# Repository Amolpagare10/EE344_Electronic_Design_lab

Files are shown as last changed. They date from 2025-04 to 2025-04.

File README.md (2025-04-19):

<!-- Modify from here -->
# Project Overview    

### Project Name: *EcoSync 8X* - A dsPIC33A microcontroller based ultrasonic guided wave structural health monitoring system
### Team Number: TUE-08

### Team Members:  
(in alphabetical order)
- **[Amol Pagare](https://github.com/Amolpagare10)**
- **[Angad Singh](https://github.com/lightning-starboy)**  
- **[Anuj Gautam](https://github.com/10Anuj)**  
- **[Anuj Yadav](https://github.com/anujyadav10457)**  
- **[Subhanshu Choudhary](https://github.com/Subhanshu-Leo)**

## Problem Statement and Solution

This project introduces an **embedded data acquisition system** using **ultrasonic guided wave–based structural inspection**. The system is built around an **8-channel transducer interface**, where each channel can be dynamically configured as either a **transmitter** or **receiver**, enabling flexible and reconfigurable testing setups—all controlled via a user-friendly **graphical user interface (GUI)**.This is the device [User Manual.](others/USER_MANUAL.pdf)

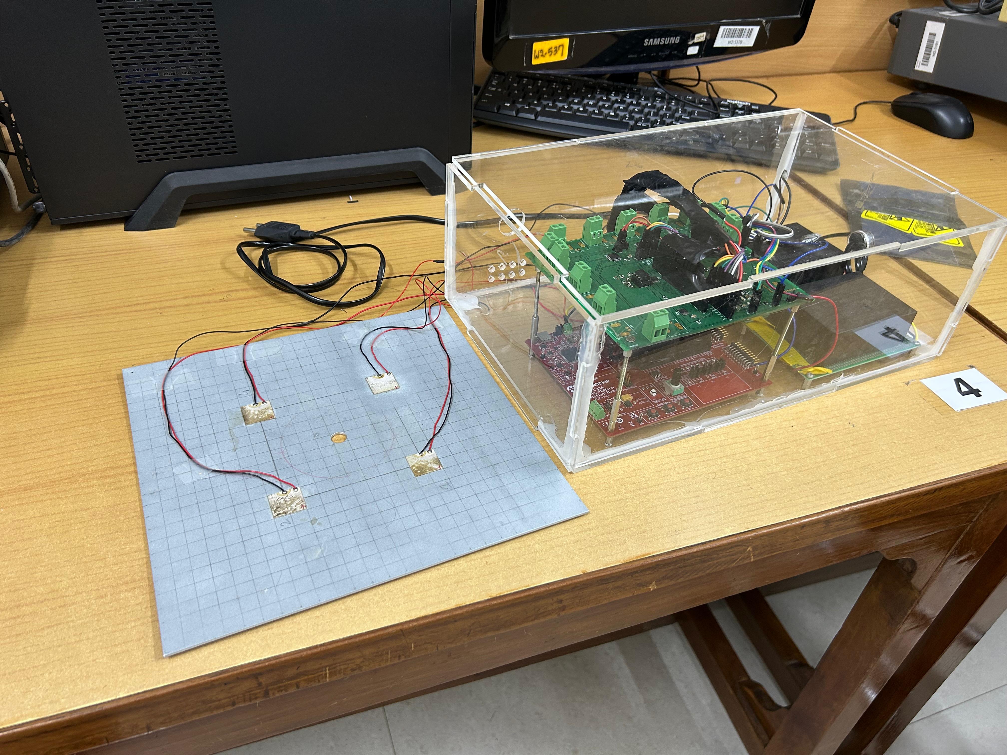
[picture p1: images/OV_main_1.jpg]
  

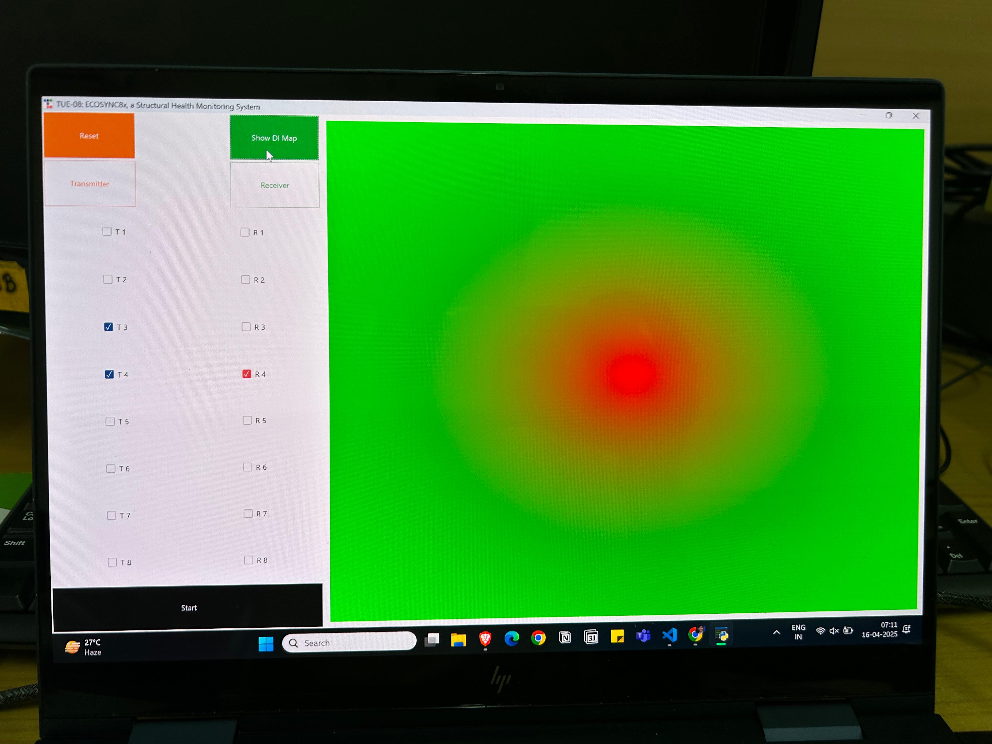
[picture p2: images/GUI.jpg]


---

### Key Features:

- **Signal Generation**: Produces a 100 kHz, 5-cycle Hanning-windowed pulse with a 10 V<sub>pp</sub> amplitude, which can be amplified up to 100 V<sub>pp</sub> using an external power amplifier.
- **Receiver Signal**: Includes high-fidelity signal acquisition with instrumentation amplifiers for accurate and noise-reduced signal capture.
- **Channel Multiplexing**: Supports 8-channel multiplexing for dynamic selection of transmitter and receiver transducers.
- **Wireless Communication**: Enables real-time data transmission to a host computer for visualization and offline analysis.
- **Structural Health Monitoring**: Ideal for applications in pipelines, metal and composite panels, and other critical infrastructure requiring long-term monitoring and inspection.
  <!-- <img src="images/" width="500"> -->

## 1. Source Code
### Project Directory Structure

```
/Project-Root
├── /src                      # Source code folder
│   ├── /dspic33ak128MC106      # Microcontroller 1
│   │   ├── integrated.c          # Handles DAC and ADC functionality
│   │   ├── command_protocol.c    # Implements the command protocol logic
│   │   ├── protocol_def.h        # Definitions for the command protocol
│   │
│   ├── /esp32                  # Microcontroller 2
│   │   ├── wifi_code.ino         # WiFi setup and communication code
```

### Programming the Microcontrollers

For programming the **dsPIC33AK128MC106** microcontroller, we used **MPLAB X IDE** in combination with the **XC-DSC compiler**.  
For the **ESP32** module, the programming was done using the **Arduino IDE**.  
In both cases, the code was written in the **C programming language**.

---

### How to Use the Code

### 1. Install Required Tools

- **MPLAB X IDE**: The official integrated development environment provided by Microchip for developing and debugging embedded applications.
- **XC-DSC Compiler**: A compiler specifically designed for 16-bit Digital Signal Controllers (DSCs) like the dsPIC33 series.

Both tools can be downloaded from the Microchip website:  
[https://www.microchip.com/en-us/tools-resources/develop/mplab-x-ide](https://www.microchip.com/en-us/tools-resources/develop/mplab-x-ide)

---

### 2. Creating a New Project in MPLAB X IDE

Once the tools are installed, follow these steps to create and configure a new project for the dsPIC33AK128MC106:

1. **Launch MPLAB X IDE**.
2. Go to the **File** menu and select **New Project**.
3. In the project wizard:
    - Select **Microchip Embedded** under **Categories**
    - Select **Application Projects** under **Projects**  
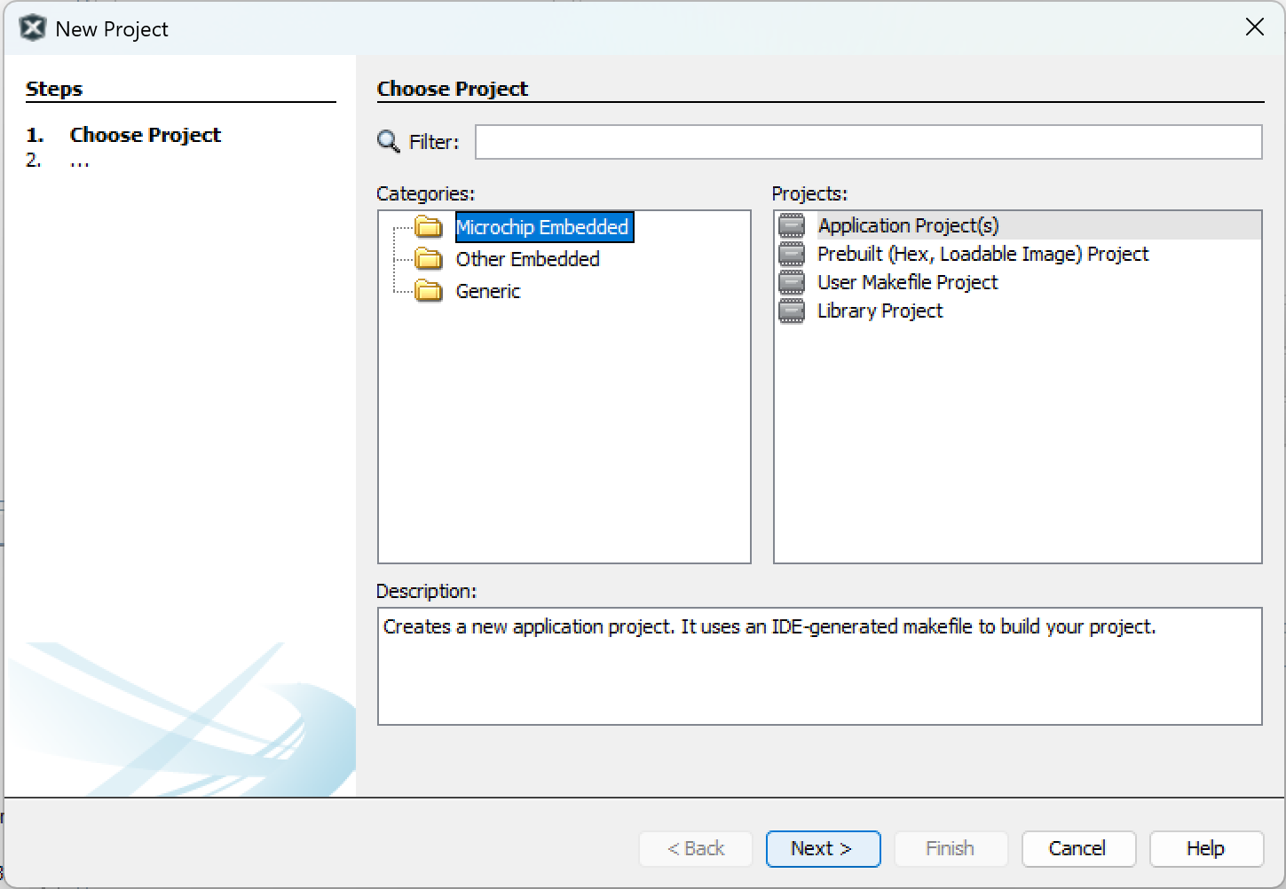
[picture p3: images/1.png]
      
4. Click **Next**, then:
    - Choose **16-bit DSCs (dsPIC33)** from the **Family** dropdown
    - Select **dsPIC33AK128MC106** from the list of devices  
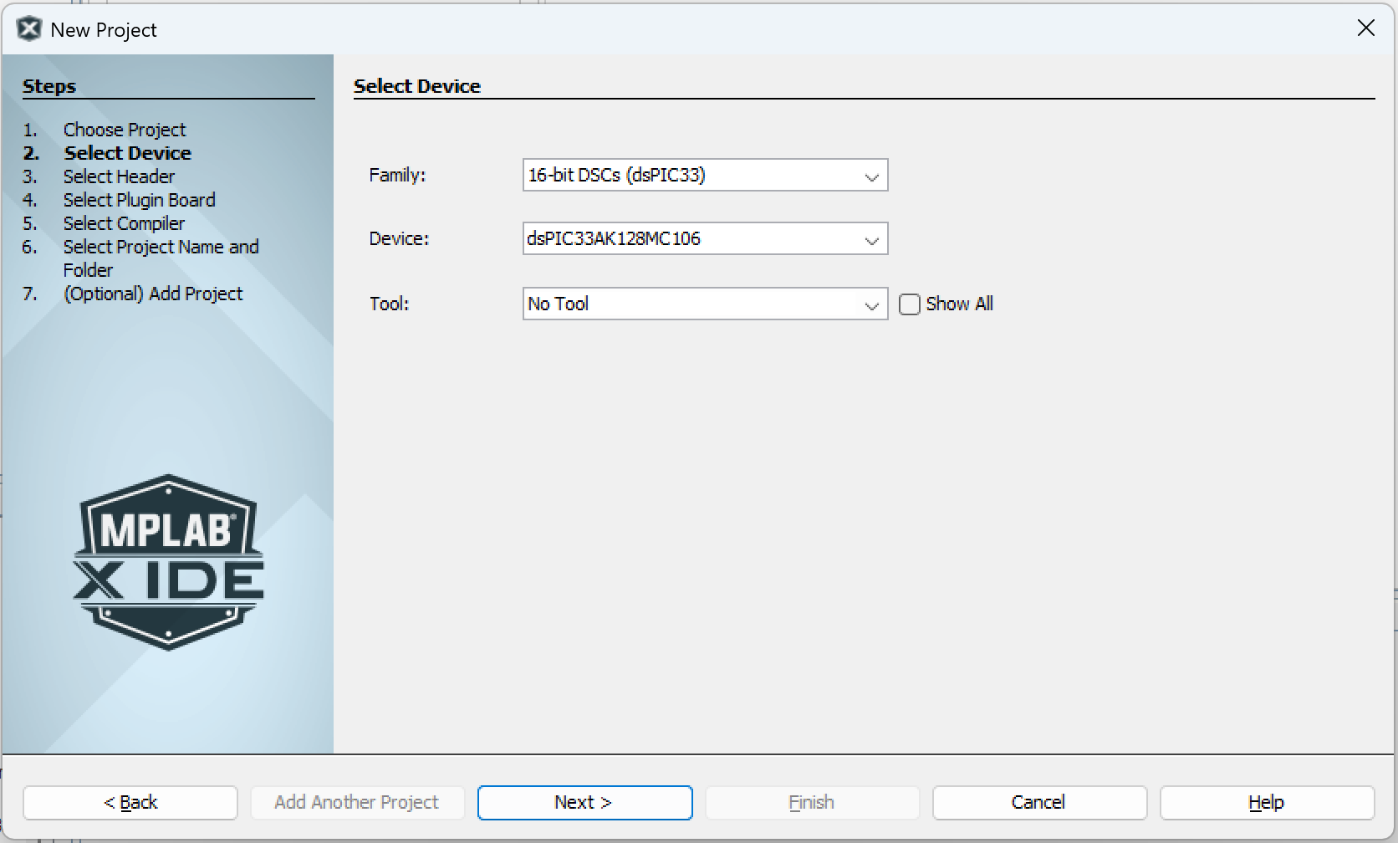
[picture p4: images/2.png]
      
5. Click **Next**, then choose the **XC-DSC** compiler from the list of available compilers  
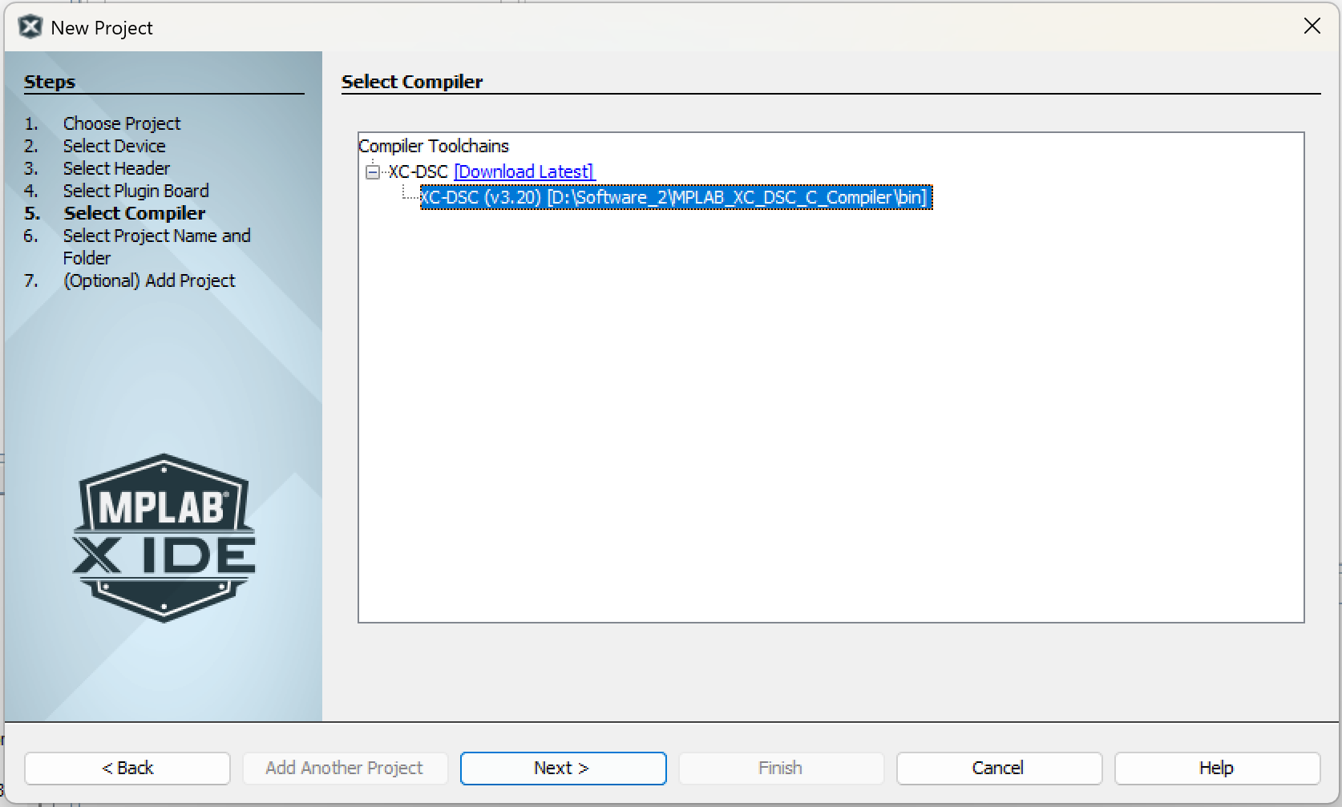
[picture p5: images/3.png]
   
6. Provide a name for your project and choose a directory where it will be saved  
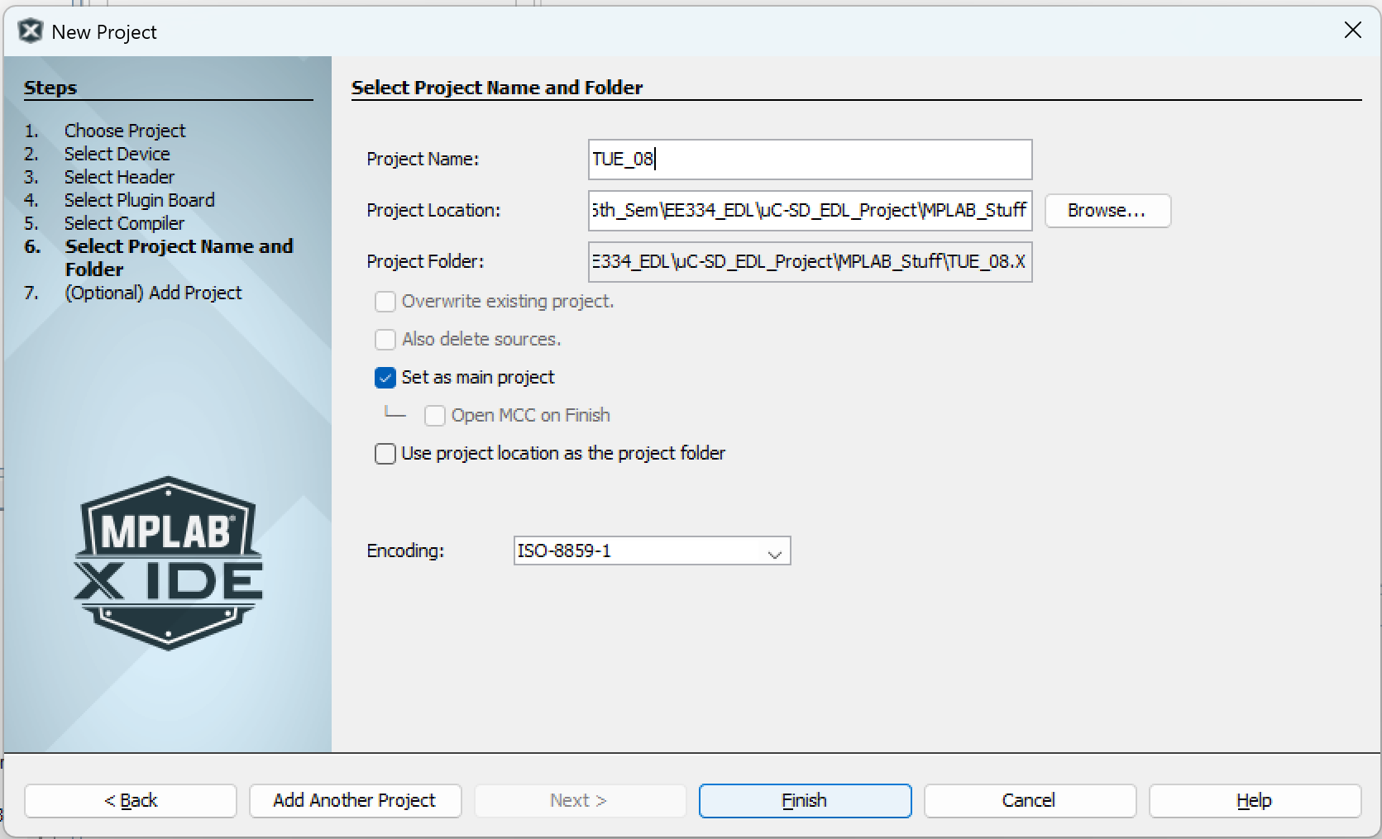
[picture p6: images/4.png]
   

---

### 3. Adding Source Code Files

Once your project is set up:

1. In the **Projects** tab within MPLAB X IDE, navigate to the `Source Files` folder.
2. Copy and paste the provided `.c` and `.h` files into the `Source Files` directory.  

---

### 4. Building and Programming the Device

To compile and upload your code:

1. Click on the **Build Project** button (hammer icon) in the toolbar to compile the code.  
   
2. After a successful build, click the **Make and Program Device** button (downward arrow icon) to upload the code to the microcontroller.  
   
3. Once the microcontroller is programmed successfully, the onboard **status LED** should start blinking, indicating that the code is running.

---

## 2. PCB Design
```
/Project-Root
├──pcb/
|  ├── pictures/                         # Existing folder
|  ├── 1N914.zip                         # Diode library
|  ├── LIB_23LCV04M-I_ST.zip            # Official library
|  ├── LIB_DAC7821IPWR.zip              # Official DAC library
|  ├── MAX1426EAI_.zip                  # ADC or other component library
|  ├── Readme.md                        # Main documentation or instructions
|  ├── design.kicad_pcb                 # KiCAD PCB layout
|  ├── design.kicad_pro                 # KiCAD project file
|  ├── design.kicad_sch                 # KiCAD schematic file
|  ├── ul_DAC7821IPW.zip                # User-provided DAC library
|  ├── ul_INA128U.zip                   # User-provided instrumentation amp
|  ├── ul_TL072CP.zip                   # User-provided op-amp library
```
We've made our PCB using KiCAD software and these are the footprints used in the PCB design.

## 3. Laser Cut Panels
### Enclosure Design and Fabrication

The enclosure for our project was custom-designed and fabricated using **laser cutting**. All design files are located in the `/3d_models` directory. The box design was created using **Autodesk Fusion 360** and exported as a **DXF file** suitable for laser cutting.
```
/Project-Root
├── /3d_models              # 3D models and laser cut files
│   ├── box_model.dxf         # DXF file with all 6 faces for laser cutting
│   ├── Box_CAD_Sketch.png    # Sketch preview of the box design
```

### Box Details

- The enclosure consists of **six interlocking acrylic panels**, each precisely designed with **notches** that fit into complementary notches on adjacent panels for seamless assembly.
- Panels are cut from **5 mm thick acrylic sheets**.
- The box is assembled using **hot glue**, which securely holds the panels together.

---

### Custom Cutouts

- **Back Panel**:
  - Includes a cutout for the **power supply**.
- **Side Panel**:
  - It has a cutout specifically for the **dsPIC33AK128MC106 microcontroller board**.
  - Below the microcontroller cutout, there are **eight holes** for the **transducer connectors**, allowing easy interfacing with the external sensors.

## 4. Bill Of Materials  
This project involves various electronic components including microcontrollers, converters, sensors, and support modules, sourced from vendors like DigiKey, Robu, Mouser, and Microchip.

### Component Overview

| **Category** | **Component** | **Quantity** | **Vendor** | **Cost (INR)** |
|---|---|---|---|---|
| **Microcontrollers & Dev Boards** | ESP32 WiFi Module, DIM Module, Development Board | 3 | DigiKey, Microchip | ₹9,457.00 |
| **Signal Conversion** | DAC, ADC, INA128 | 3 | Mouser, DigiKey, Robu | ₹1,910.00 |
| **Power Modules** | SMPS (x2), Buck & Boost Converters | 5 | DigiKey, Robu | ₹4,420.00 |
| **Sensors** | PZT Sensor (SP-5H) | 8 | CPS Lab | ₹40,000.00 |
| **Misc ICs** | MUX, Electronic Switch, Opamp | 3 | Mouser, DigiKey, Robu | ₹2,675.00 |
| **Mechanical** | Acrylic Sheet Panels (Laser Cut) | 6 | WEL | NA |

---

### **Total Cost**: ₹58,462.00

> Note: Cost for acrylic sheets not included.

## **Learning, Experiences, Hardships, and Difficulties Encountered**

<!-- This course has been a valuable learning experience for us. It taught us how to transform an idea into a tangible product, which was both challenging and exciting. Throughout the project, we experienced highs when things were progressing smoothly, when our DAC wasn't giveing the correct waveform, as well as lows when nothing seemed to work despite our efforts, when our ADC couldnt't work reliably. There were moments of frustration, especially when technical setbacks slowed us down or when not all team members could contribute equally due to other academic commitments, even when we had quizes and exam, we tried to invest some time according to our free timings. In hindsight, we believe a more effective distribution of tasks could have helped us manage these challenges better. Nonetheless, the journey was immensely enriching, and we’re grateful for the opportunity to learn and grow through this experience. -->

This course has been a valuable learning experience for us. It taught us how to transform an idea into a tangible product, which was both challenging and exciting. 

Throughout the project, we experienced several highs—such as when things were progressing smoothly—and lows, like when our DAC wasn't giving the correct waveform or when our ADC couldn’t work reliably. 

There were moments of frustration, especially when technical setbacks slowed us down or when not all team members could contribute equally due to other academic commitments. Even during quizzes and exams, we tried to invest time according to our free schedules.

In hindsight, we believe a more effective distribution of tasks could have helped us manage these challenges better. Nonetheless, the journey was immensely enriching, and we’re grateful for the opportunity to learn and grow through this experience.

## Current status and Future Prospects for our Project

---

### 1. Partially Incomplete ADC

#### What Was Done:
- Tested the ADC on the PCB using waveform inputs from the INA.
- Output signal remained constant across tests.
- Tried using an earlier-working ADC on a breadboard—still observed a constant output.

#### Unresolved Issues:
The root cause remains unidentified. Potential issues could include:
- Incorrect voltage reference.
- INA output entering saturation.
- Firmware misconfiguration.
- Inaccurate or missing clock signals.

#### Parts Not Completed:
- Full integration of the ADC into the signal chain.
- Validation using real digitized sensor data.
- Establishing a complete end-to-end data acquisition pipeline for signal processing.

---

### 2. Partially Incomplete Wi-Fi Module Interface

#### What Was Done:
- Attempted UART-based interfacing of the Wi-Fi module with the Curiosity board.
- Identified that the UART pins on the board were non-functional.

#### Progress Made:
- Successfully interfaced the Wi-Fi module with a GUI.
- Enabled both data transmission and reception.
- Initially received garbage data when connected to a laptop, resolved by:
  - Splitting the code into two modules:
    - One for the Wi-Fi module at **115200 baud rate**.
    - One for laptop communication at **9600 baud rate**.

#### Parts Not Completed:
- Wi-Fi integration with the Curiosity board.
- Wireless transmission of sensor data from the MCU.
- Real-time wireless data logging and remote visualization.

---

## Future Prospects

### 1. Enhanced GUI Interface
- Develop a more intuitive and interactive GUI.
- Key features to include:
  - Real-time waveform plotting.
  - Diagnostic alerts for system anomalies.
  - Interactive signal control and parameter tuning.

### 2. DI Map Algorithm Improvements
- Optimize the **Damage Index (DI)** mapping algorithm for better defect localization and embedded performance.
- Add a validation metric to evaluate and improve accuracy.
- Enable dynamic updates on the GUI for visual feedback.

### 3. Complete Wi-Fi Module Integration
- Finalize integration of the Wi-Fi module with the Curiosity board.
- Support seamless, real-time wireless data transmission.
- Enable remote monitoring through a web interface or mobile application.

### 4. SRAM-Based Memory Expansion
- Integrate external **SRAM** to overcome microcontroller memory limitations.
- Support:
  - High-resolution signal logging.
  - Buffered data acquisition.
  - Advanced signal processing tasks on-device.

---

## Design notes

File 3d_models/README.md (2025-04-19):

# Enclosure Design and Construction
We had a simple enclosure design for our project, which was primarily focused on housing the electronics and providing access to the necessary ports. 

## Design Software
- The enclosure was designed using **Autodesk Fusion 360**, which provided a 3D parametric design environment.
- The final laser-cut layout was exported as a **DXF (Drawing Exchange Format)** file, the industry-standard format for 2D cutting paths.

---

## Box Construction Details

- **Material**: The panels were cut from **5 mm thick clear acrylic sheets**, offering a good balance between strength and aesthetics.
- **Structure**: The enclosure consists of **six interlocking panels** — top, bottom, front, back, and two sides.
- **Joinery**:
  - Each panel has precisely aligned **notches and tabs**, allowing them to fit together like puzzle pieces without additional fixtures.
  - These interlocks reduce the need for mechanical fasteners and improve ease of assembly.
- **Assembly**:
  - The panels are joined using **hot glue**, which offers strong adhesion while being easy to apply.
  - The enclosure is lightweight, transparent for visual inspection, and sturdy enough to house electronics safely.

---

## Custom Cutouts and Access Ports

Each panel was carefully designed with cutouts for interfacing components and ease of access:

- **Back Panel**:
  - Includes a circular slot for the **power supply input**.
  - Ensures that the AC-DC SMPS module or USB-powered units can be neatly connected without internal clutter.

- **Side Panel (Control Interface Panel)**:
  - Features a precise cutout for the **dsPIC33AK128MC106 microcontroller board** so that its USB/debug port remain externally accessible.
  - **Below the microcontroller**, there are **eight circular holes** which allow the connections to the **transducer connectors**.
    - These connectors interface with external **piezoelectric sensors**, and the holes ensure that cables can be plugged in directly without disassembling the box.

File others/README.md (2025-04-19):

# Graphical User Interface (GUI) Overview

Our GUI allows users to configure the **transmitter** and **receiver** setup of the transducers.

- Once the desired configuration is selected, users can **start transmission and reception** of ultrasonic signals.
- The results are then visualized on the GUI using a **HeatMap**.
- Currently, the **HeatMap is based on a pipe algorithm**, as the **Damage Index algorithm for plates** is still under study.
- For demonstration purposes, the pipe-based visualization will be used.

---

# User Manual – Key Instructions

## 1. Sensor Placement
- Mount piezoelectric sensors firmly on the plate following a planned layout.
- Maintain consistent spacing and ensure solid mechanical coupling.
- Clearly label each sensor for easy identification when assigning Tx/Rx roles.

## 2. Power Connection
- Plug the system into a **220V, 15A grounded socket**.
- Avoid using damaged plugs or loose/multi-plug extensions.
- This power connection supports the signal generation and data acquisition modules.

## 3. Wi-Fi Connection
- Connect your computer to the **Wi-Fi network** broadcast by the control box.
- No internet is needed — this is a local wireless connection.
- Ensure that firewall or antivirus settings do not block the communication port.

## 4. Sensor Configuration in Application
- Launch the **SHM (Structural Health Monitoring)** software.
- Assign transducers as **Transmitters (Tx)** and **Receivers (Rx)** via the interface.
- Choose sensor pairs that offer optimal coverage for the structure being analyzed.

## 5. Data Reception & DI Map Generation
- After configuration, signal data will be transmitted and collected.
- Once data is received, click the **orange button** in the GUI to generate the **Damage Index (DI) Map**.
- The DI Map highlights potential damage zones based on signal response characteristics.

---

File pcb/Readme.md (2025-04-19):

# PCB Design Issues:

- Our SMD INA on the PCB was not working. We replaced it with another SMD INA, but it still didn't work. Since we didn’t have any more SMD INAs, we used a DIP INA on a breadboard and connected it to the PCB — and it started working.

- In the ADC, we grounded the CMLP pin (pin 11), as the datasheet mentioned that for DC coupling, it should be grounded. However, during breadboard testing, we found that it worked when connected to 5V instead.

- Even after all this, the ADC on the PCB is still not working. We tried to figure out the issue by checking if the clock is working, if we are receiving data at the ADC, and if the power supply to the ADC is correct. We found that everything appears to be in order, yet we are still not receiving any data from the ADC.

# Purpose of the PCB:

- In our project, almost everything relied on the PCB. We had to use components like the DAC, TL072, power amplifier, electronic switch, multiplexer, INA, and ADC — all of which required reliable and organized connections. Using a PCB was the best choice to ensure clean and consistent wiring.

- Moreover, we found that small mistakes on the breadboard made debugging very cumbersome. In contrast, the PCB allowed us to make all the connections properly and verify them once. After the PCB arrived and we tested it, we could trust the setup and focus on the actual performance of the circuit.

# Explanation of PCB connections 

- Our microcontroller was connected to the DAC to convert digital data into analog signals. The signal was then passed through a TL072 and a power amplifier to amplify it. Next, an electronic switch was used to select which transducer would transmit the signal.

- After transmission, a multiplexer (MUX) was used to select the transducer that would receive the signal. The received signal was then passed through an INA and a clipper — the INA amplified the signal, while the clipper limited high voltages to protect the circuit.

- Finally, the processed analog signal was fed into an ADC to convert it back into digital form, which was then sent to the PC for post-processing.

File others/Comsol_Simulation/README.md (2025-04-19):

# Piezoelectric Sensor Excitation Simulations (COMSOL)

This repository contains simulation results from **COMSOL Multiphysics** illustrating various excitation scenarios of piezoelectric sensors embedded on a solid structure. The aim of these simulations is to study wave propagation and stress distribution in the material in response to controlled excitations.

---

## Overview

Piezoelectric sensors are commonly used in **Structural Health Monitoring (SHM)** systems to detect and localize defects through guided wave techniques. This project investigates how different excitation methods and sensor placements affect wave propagation and energy concentration in a simulated environment.

---

## Simulation 1

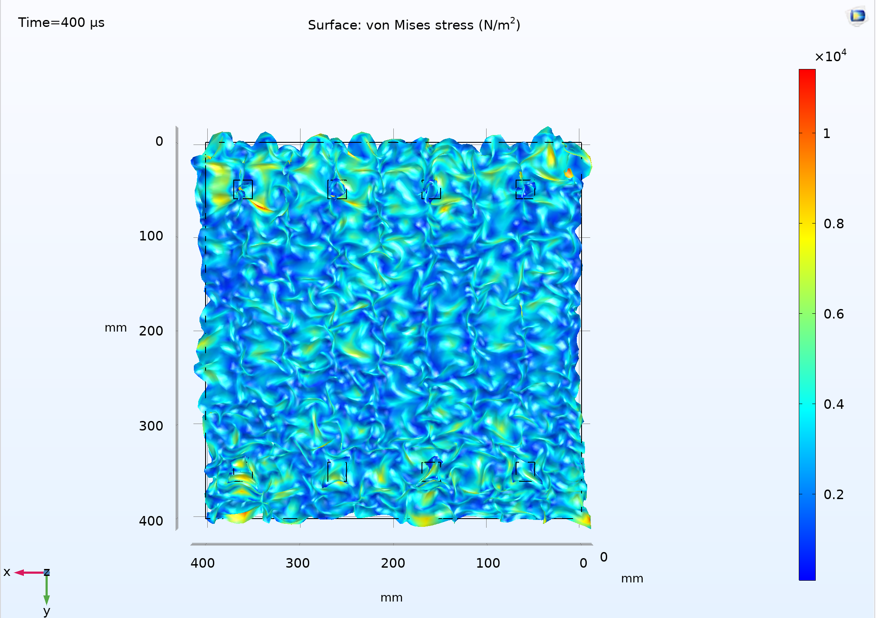
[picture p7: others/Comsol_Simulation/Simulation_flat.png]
Flat Plate view at 400µs


**Description:**  
This image shows wave propagation across the plate after excitation via PZT sensors, observed when the plate is placed flat.

---

## Simulation 2

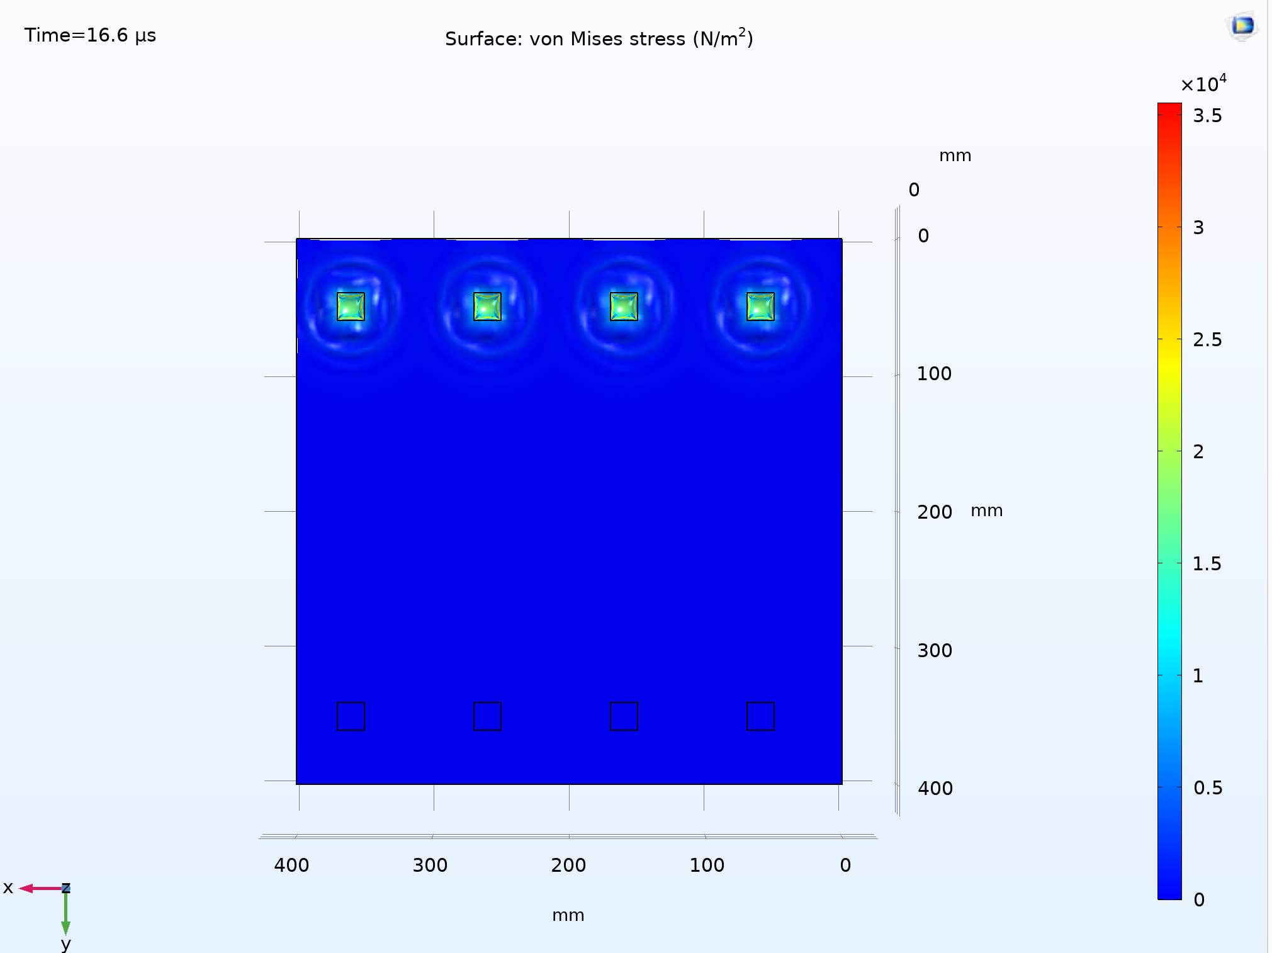
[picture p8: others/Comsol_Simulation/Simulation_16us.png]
Plate 16.6µs after excitation


**Description:**  
This snapshot captures the state of the plate 16.6µs after excitation of all four PZT sensors.

---

## Simulation 3

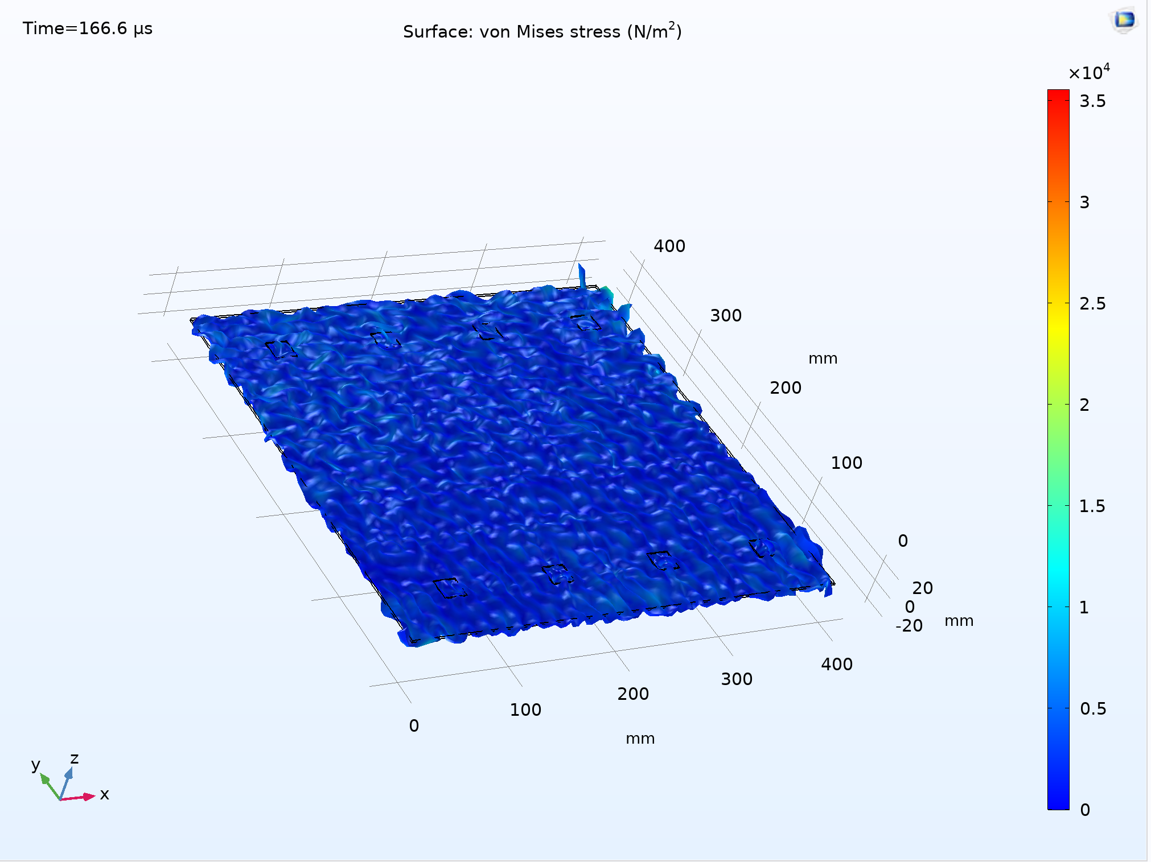
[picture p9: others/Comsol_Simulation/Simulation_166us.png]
Plate 166.6µs after excitation


**Description:**  
At 166.6µs, guided waves have begun traversing the plate and the wavefronts are clearly visible.

---

## Simulation 4

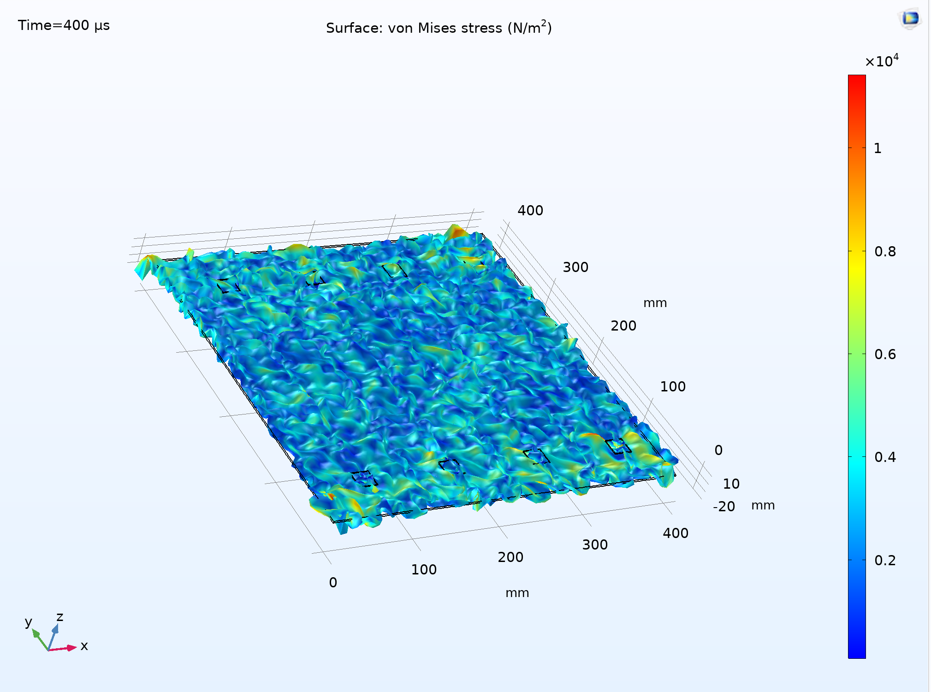
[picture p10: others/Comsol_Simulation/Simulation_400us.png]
Plate 400µs after excitation


**Description:**  
This image represents the final stage where guided waves have propagated across the entire plate at 400µs after excitation.

---

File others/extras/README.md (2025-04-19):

# Breadboard Testing Results

This document summarizes the testing stages and results of different components in the system including the Command Protocol, DI Map Algorithm, DAC Output, Electronic Switch, Multiplexer, and Instrumentation Amplifier (INA).

---

## Command Protocol

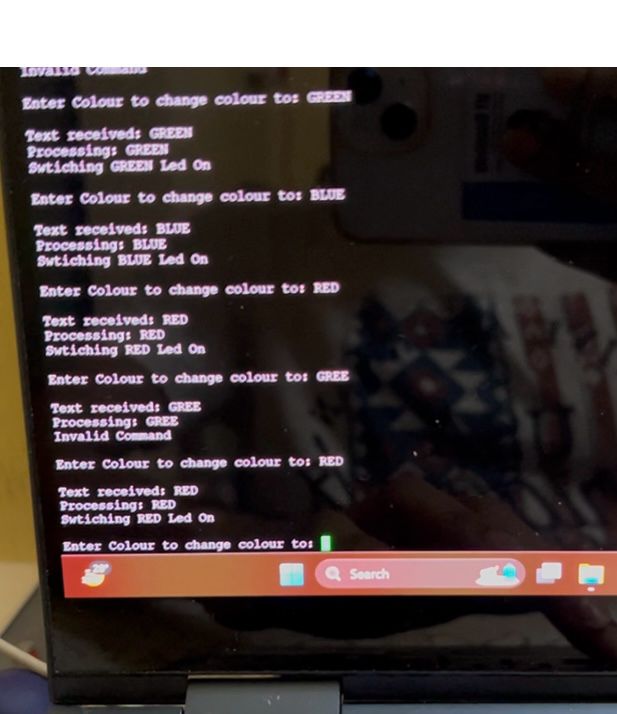
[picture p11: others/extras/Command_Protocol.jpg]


The above image shows the testing of our **Command Protocol**. The protocol is functioning correctly, as the appropriate LED lights up when the corresponding command is sent to the microcontroller. This confirms successful communication and command parsing.

---

## DI Map Algorithm

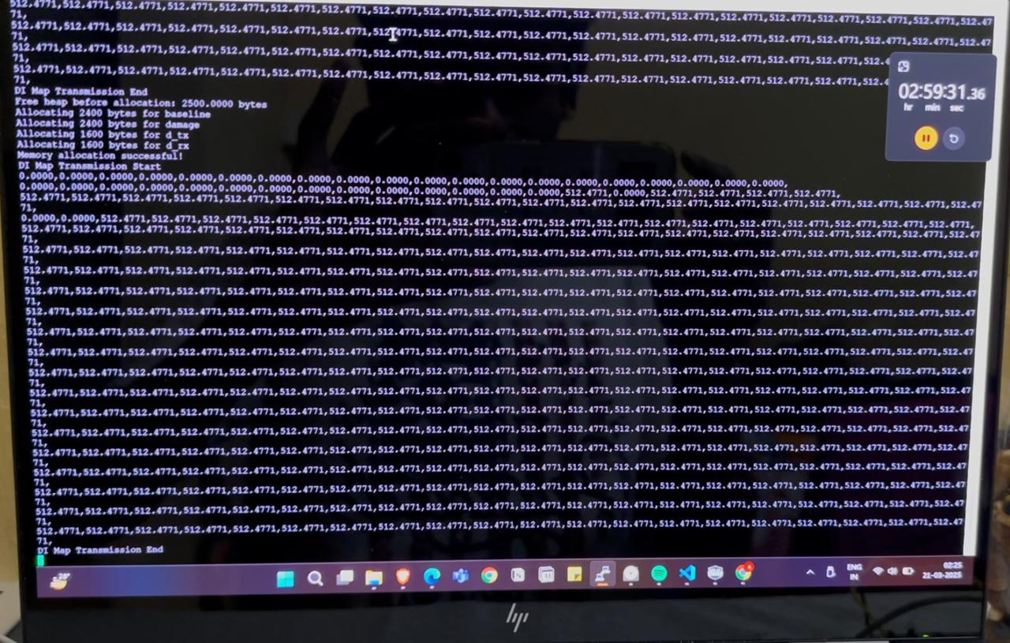
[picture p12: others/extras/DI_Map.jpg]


The **DI Map Algorithm** computes the **Damage Indices (DI)** for each coordinate in the grid. The testing confirms the algorithm accurately maps the DIs, ensuring reliable diagnostics of the structural health for each node in the system.

---

## DAC Output

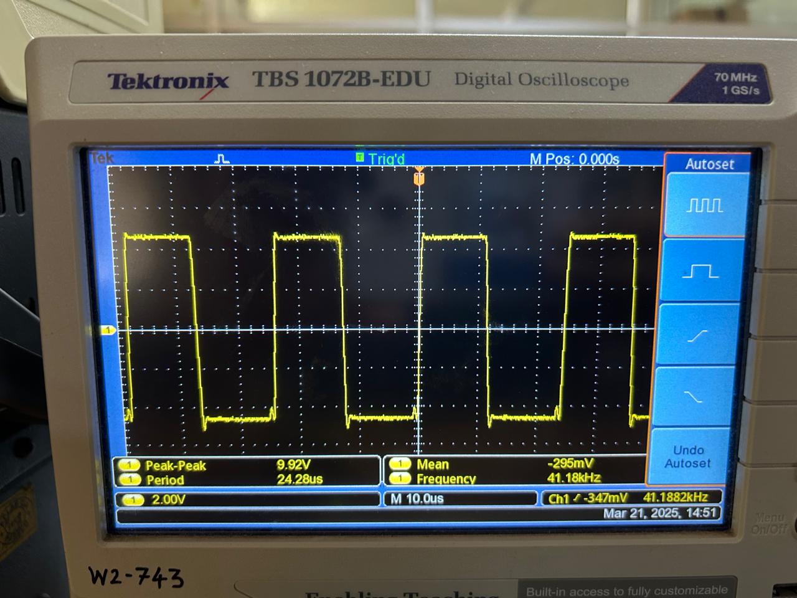
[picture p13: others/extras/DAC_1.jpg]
  
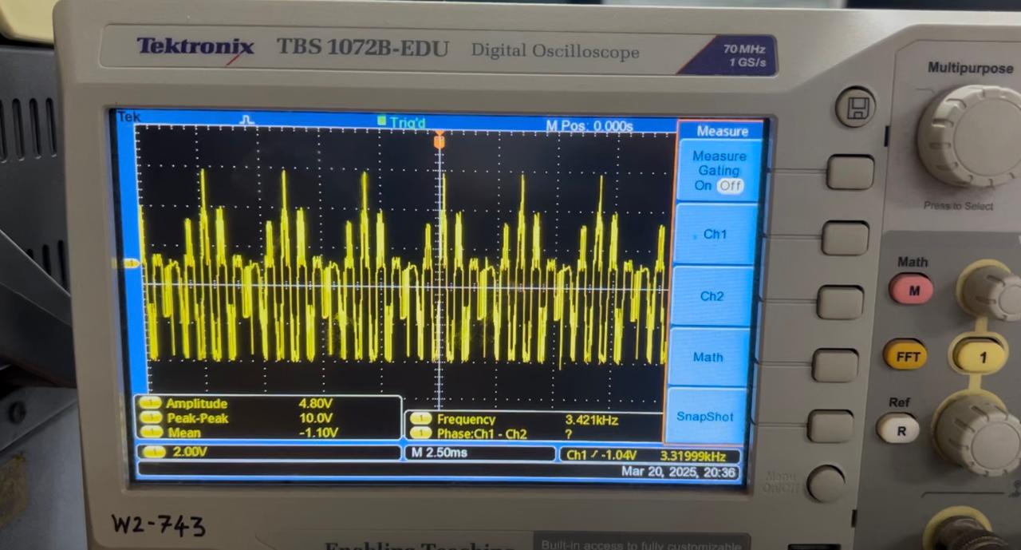
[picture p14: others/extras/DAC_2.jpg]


The above images display intermediate testing results of the **Digital-to-Analog Converter (DAC)** output. Two waveform types were tested:
- A **square wave**
- A **Hanning pulse**

These waveforms were successfully generated, indicating that the DAC configuration and output logic are functioning as intended.

---

## Electronic Switch

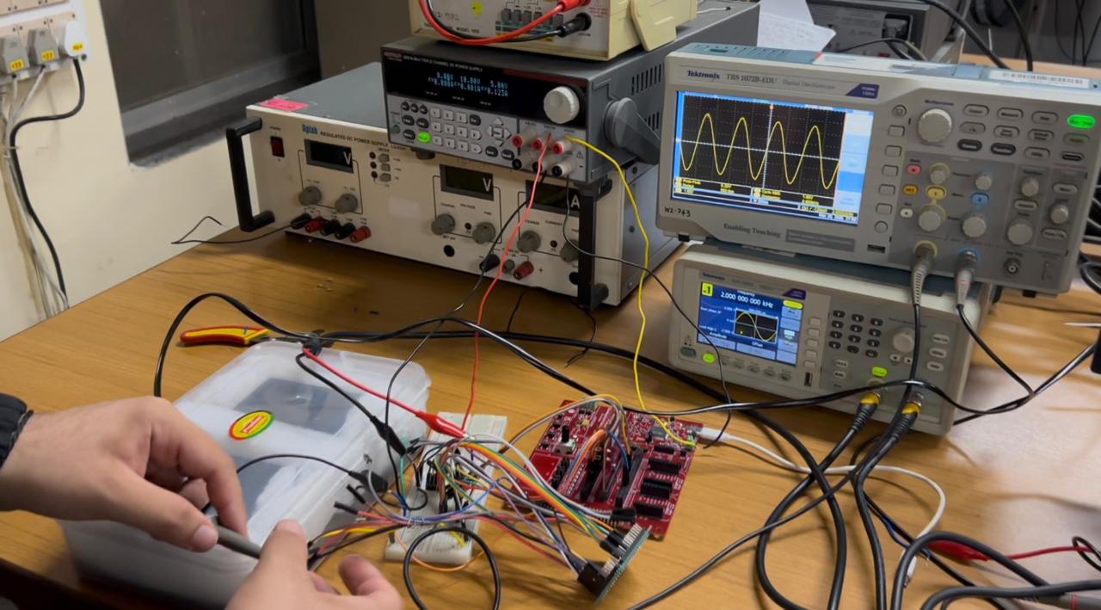
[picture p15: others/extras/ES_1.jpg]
  
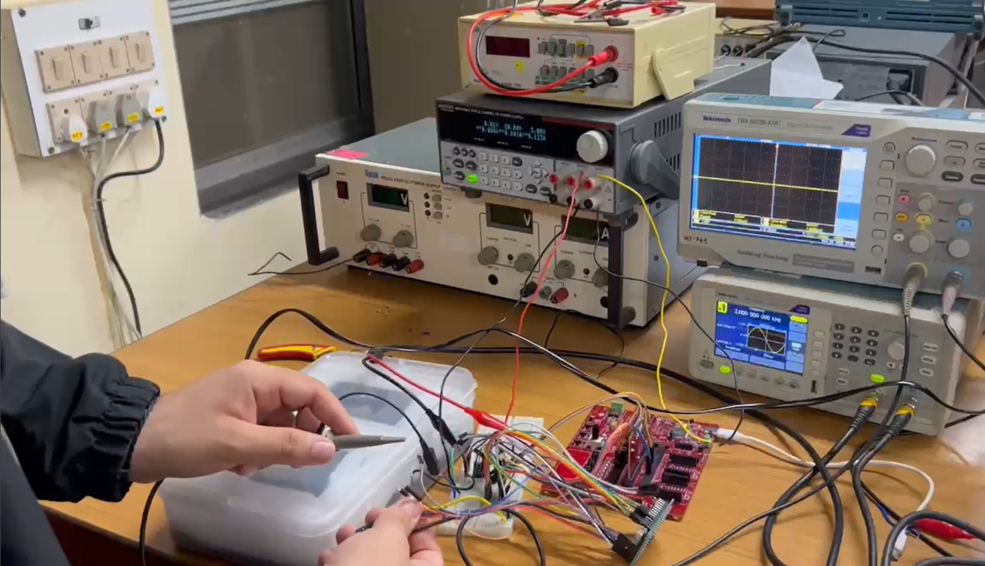
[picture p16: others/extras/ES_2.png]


The images above show the **Electronic Switch** test results. Upon correct selection of the switch, the appropriate waveform is transmitted to the DAC. This validates the proper operation of the switch selection and signal routing mechanism.

---

## Multiplexer (MUX)

### MUX 1

**Input:**  
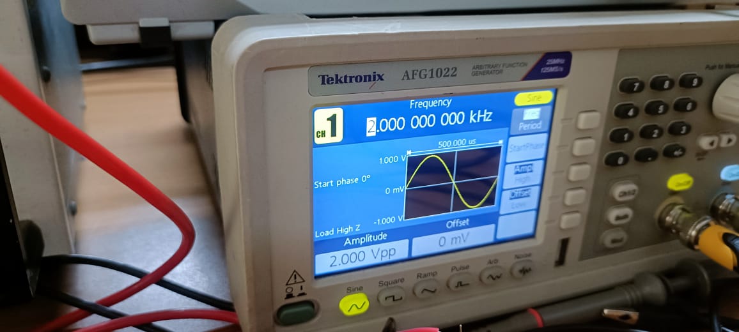
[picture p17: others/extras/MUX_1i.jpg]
  

**Output:**  
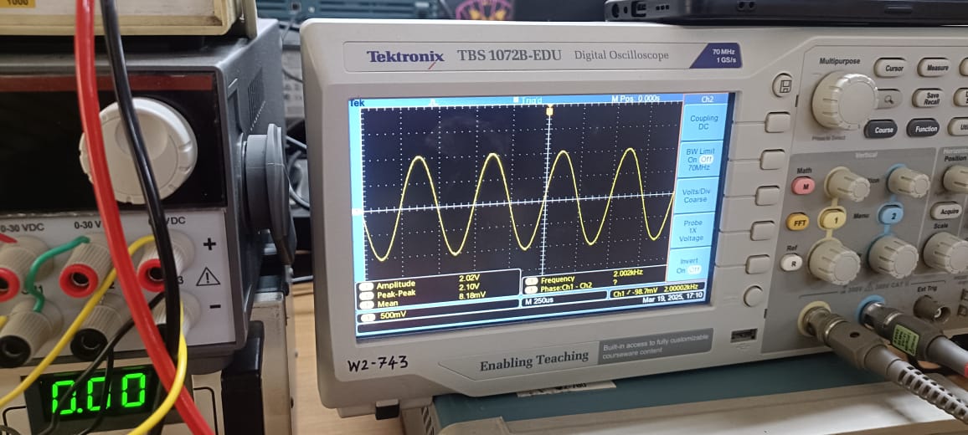
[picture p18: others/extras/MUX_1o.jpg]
  

### MUX 2

**Input:**  
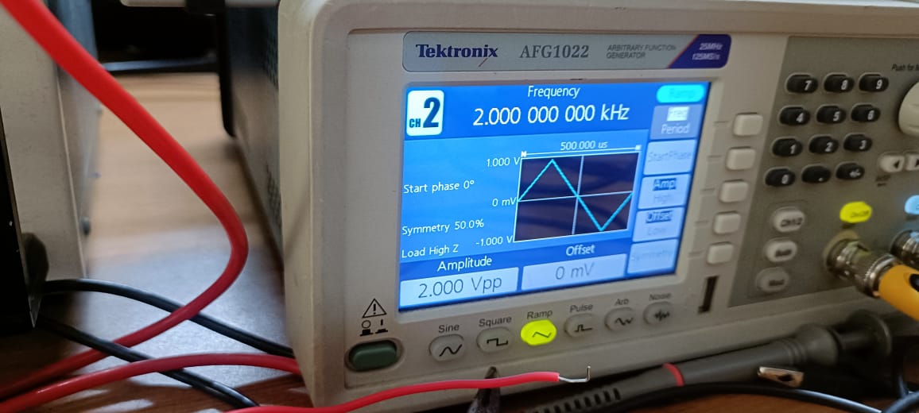
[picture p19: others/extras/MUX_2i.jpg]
  

**Output:**  
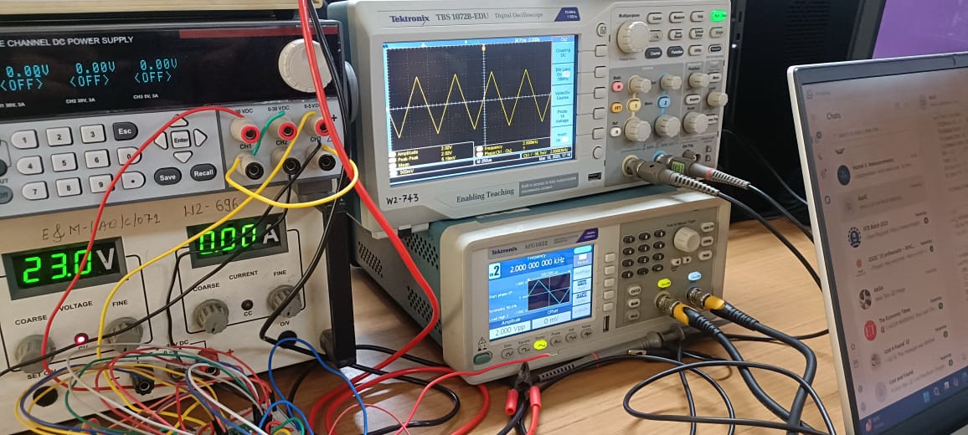
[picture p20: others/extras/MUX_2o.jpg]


The above results demonstrate the functionality of the **Multiplexer (MUX)**. For both MUX 1 and MUX 2, the output waveforms correspond correctly with the selected inputs, validating the signal selection and transmission through the MUX circuitry.

---

## Instrumentation Amplifier (INA)

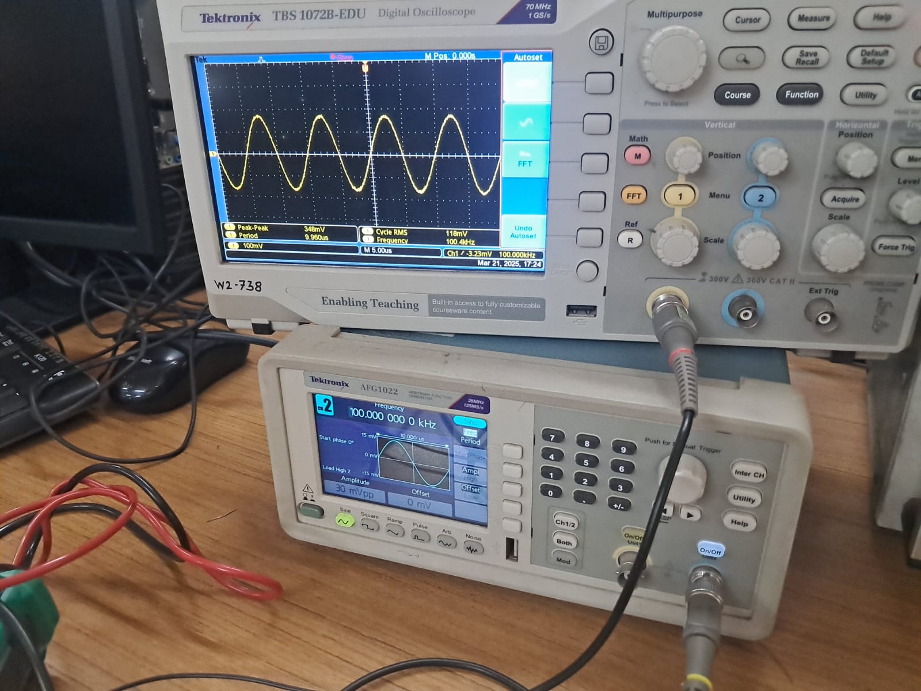
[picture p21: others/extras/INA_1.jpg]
  
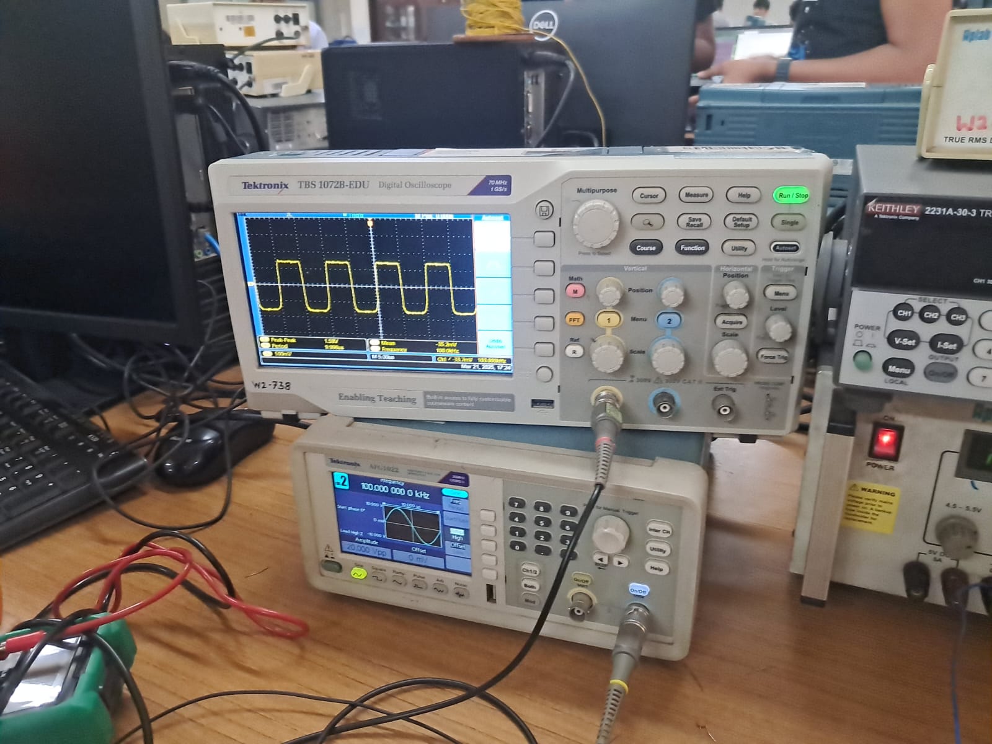
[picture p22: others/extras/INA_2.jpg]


The **Instrumentation Amplifier (INA)** testing is shown above:
- The **first image** confirms that when the voltage is below the threshold level, the signal is not clipped.
- The **second image** shows that once the voltage exceeds the threshold, the signal is correctly clipped.

This behavior confirms that the INA is performing the expected threshold-based signal conditioning.

---

## Summary

All components of the system have been individually tested and verified:
- Command Protocol and DI Mapping Logic are functioning correctly.
- DAC outputs accurate waveforms.
- Electronic Switch and MUX route signals correctly.
- INA clips signals only when threshold is crossed.

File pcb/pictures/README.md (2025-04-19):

## PCB Design and Layout

This section showcases the **Printed Circuit Board (PCB)** design and layout for the system. The PCB was meticulously designed to integrate all key components such as the microcontroller, DAC, multiplexer, electronic switch, and supporting circuits, while maintaining a compact and efficient footprint.

---

### 3D Rendered Views

The following images show 3D representations of the fabricated PCB, providing a clear understanding of the component placement and structural design:

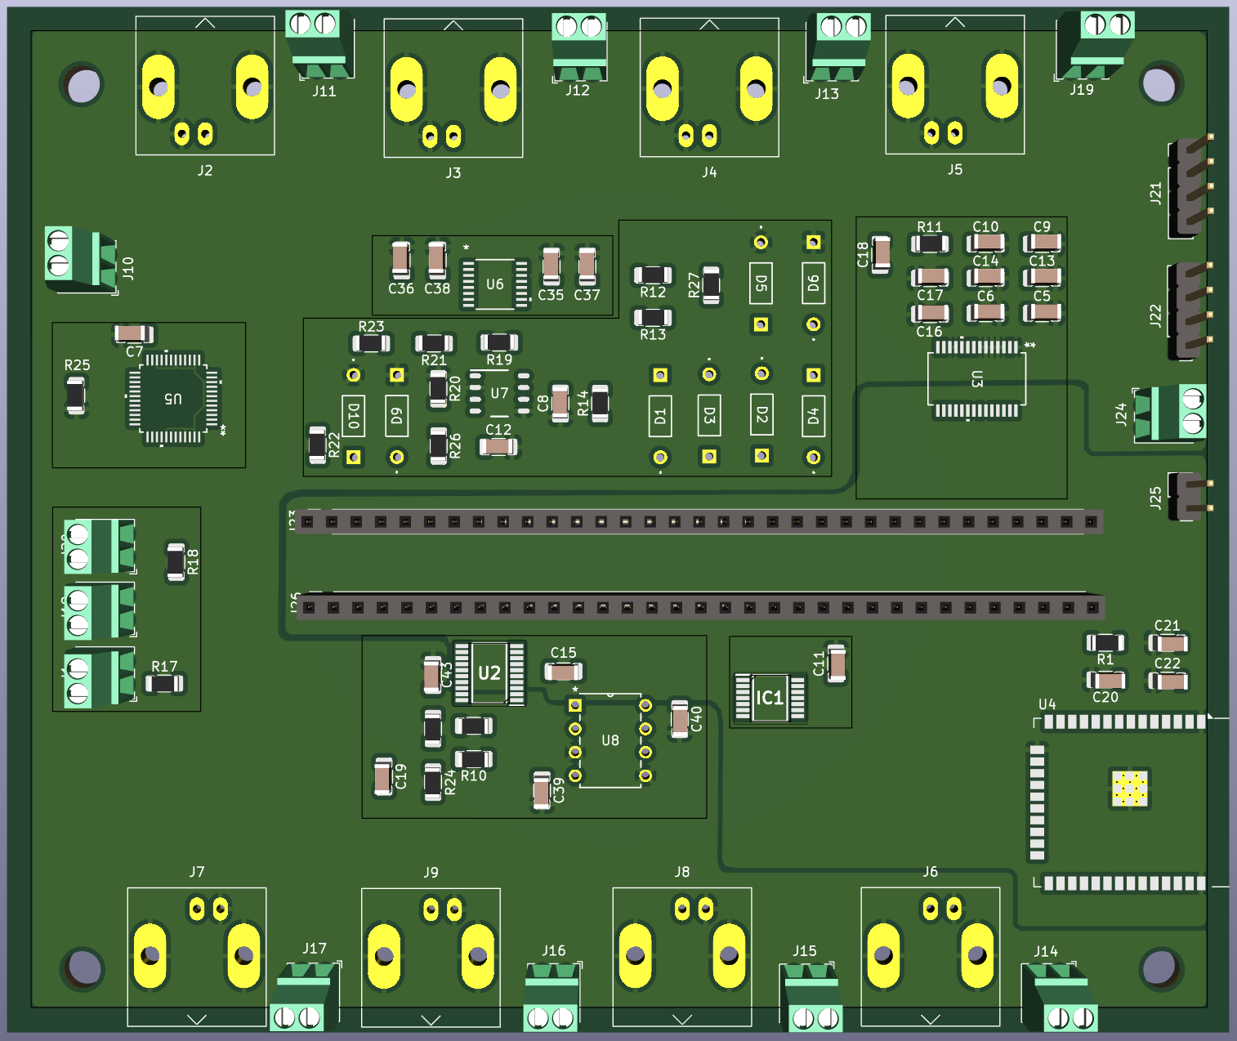
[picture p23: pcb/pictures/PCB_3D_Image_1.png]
     

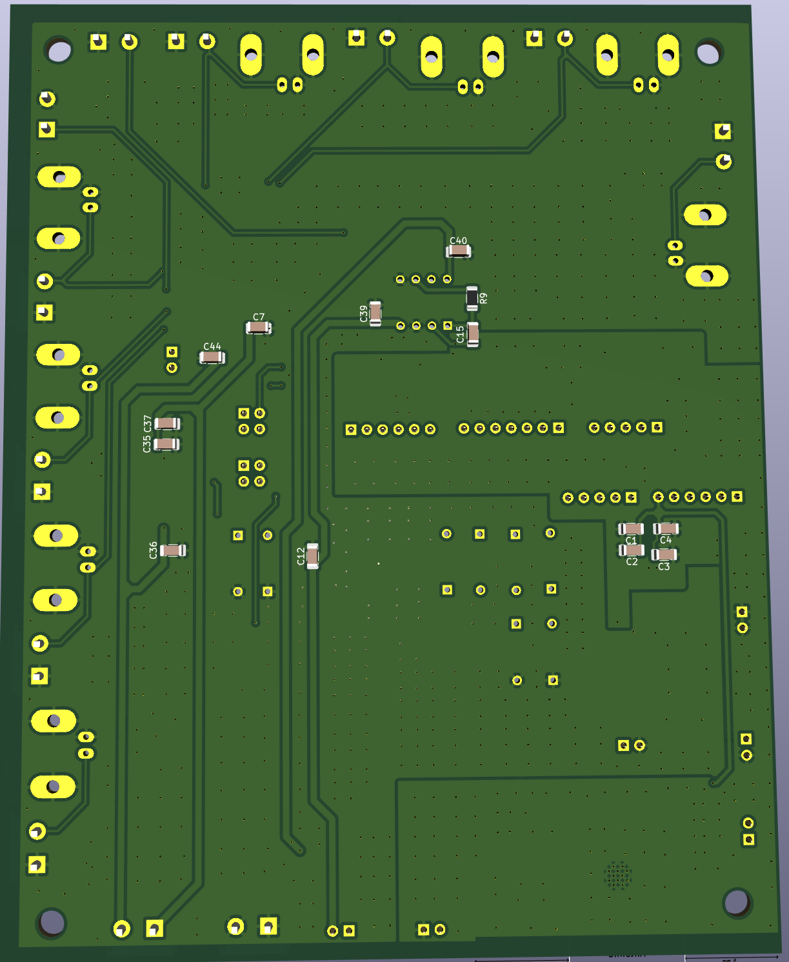
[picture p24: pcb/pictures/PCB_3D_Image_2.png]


- These 3D images help in visualizing the final assembly of the hardware.
- Components are placed logically to optimize signal routing and minimize interference.
- The design ensures that all connectors and test points are accessible for debugging and verification.

---

### PCB Layout (Top and Bottom Views)

The images below display the PCB layout used for fabrication, including the routing of tracks, via placement, and component outlines.

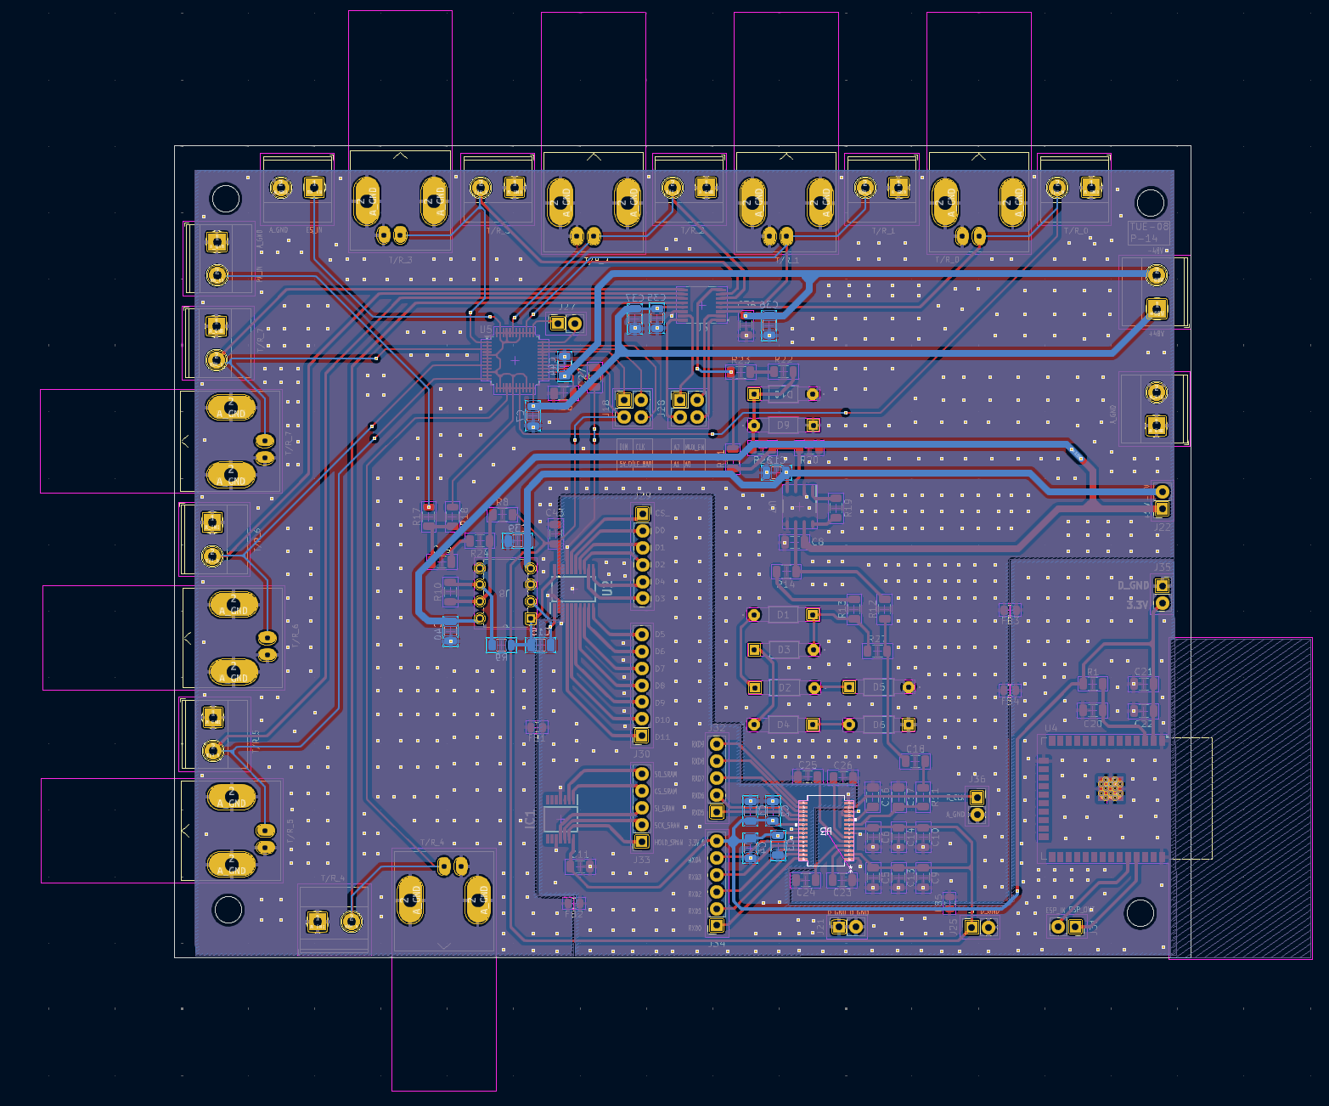
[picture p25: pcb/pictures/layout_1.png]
     
 
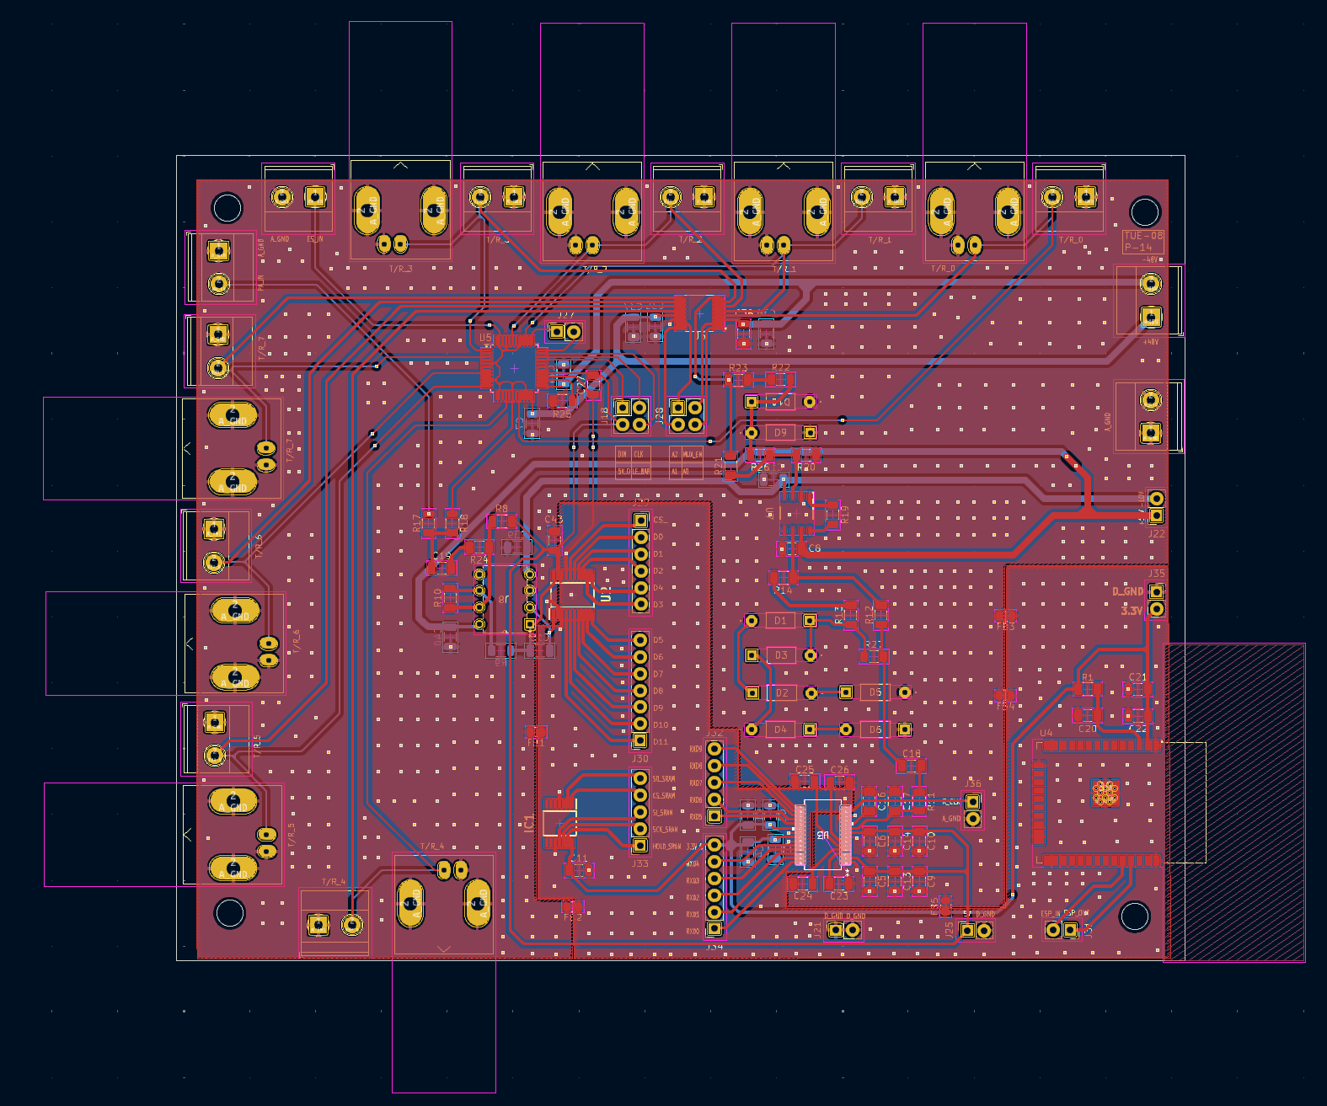
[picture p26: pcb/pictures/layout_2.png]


- The **first layout** image highlights the **top copper layer**, showing signal traces and footprints of surface-mounted and through-hole components.
- The **second layout** shows the **bottom layer**, including ground fills, power routing, and additional signal traces.

These layouts were exported from the PCB design tool post-routing and silkscreen labeling. Care was taken to follow **design-for-manufacturing (DFM)** and **design-for-test (DFT)** guidelines to ensure reliable production and ease of testing.

---

### Summary

The PCB design phase has been successfully completed with:
- Optimized layout for signal integrity and power distribution.
- Verified component placement via 3D views.
- Clearly separated analog and digital sections for noise reduction.

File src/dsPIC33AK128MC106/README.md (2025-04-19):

# Firmware Overview

This project involves two main microcontrollers — the **dsPIC33AK128MC106** and the **ESP32**, working in synchrony to perform data acquisition and communication over WiFi.

---

## dsPIC33AK128MC106 Firmware

The **dsPIC33AK128MC106** microcontroller is responsible for **low-level control** of the hardware, including analog signal acquisition, multiplexing, DAC output, and switching logic.

### Files and Their Responsibilities

- **`integrated.c`**
  - This file manages all the core hardware control functionalities:
    - **ADC (Analog-to-Digital Converter)**: Captures analog signals from selected sensors.
    - **DAC (Digital-to-Analog Converter)**: Outputs processed signals or control voltages.
    - **Multiplexer Control**: Selects one of many inputs to be routed for ADC/DAC operations.
    - **Electronic Switch Control**: Activates/deactivates specific parts of the circuitry based on the command received.
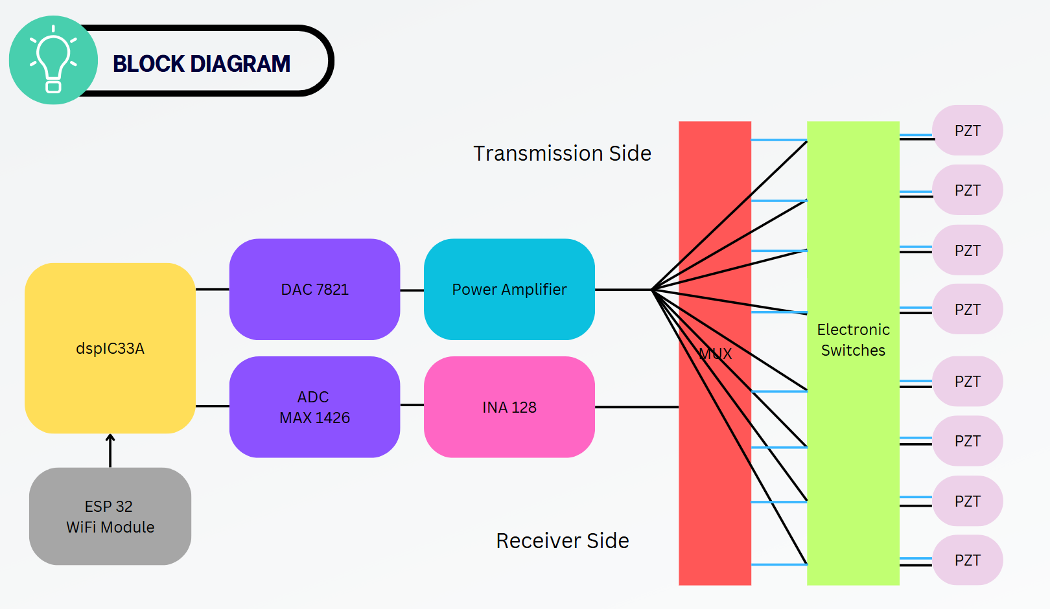
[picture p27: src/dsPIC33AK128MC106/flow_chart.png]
    - 

- **`command_protocol.c`**
  - Implements the custom **command parsing logic**.
  - Interprets incoming commands from the ESP32 via UART and maps them to appropriate actions (e.g., switch control, channel selection).
  - Works closely with the `integrated.c` module to set the system state accordingly.

- **`protocol_def.h`**
  - Header file containing definitions, constants, and macros related to the command protocol.
  - Ensures consistency across modules when referring to commands or states.

---

## GUI-Driven Command Flow

A custom GUI sends **structured commands** over UART to the **dsPIC33AK128MC106**. These commands follow a defined protocol:

1. GUI sends a command to the dsPIC via UART.
2. `command_protocol.c` interprets the command.
3. Based on the command:
   - The **Multiplexer** selects the appropriate input channel.
   - The **Electronic Switch** is toggled ON/OFF accordingly.
4. Signal acquisition or output happens via **ADC/DAC** as requested.

---

## System Overview Diagram

    [GUI] ← WiFi → [ESP32] ←UART→ [dsPIC33AK128MC106]
                                      |
                  ┌───────────────────┼────────────────────┐
                  ▼                   ▼                    ▼
              [Multiplexer]     [Electronic Switch]     [ADC/DAC]

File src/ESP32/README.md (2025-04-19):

# Firmware Overview

This project involves two main microcontrollers — the **dsPIC33AK128MC106** and the **ESP32**, working in synchrony to perform data acquisition and communication over WiFi.

---

## ESP32 WiFi Module (Arduino-based)

The **ESP32** microcontroller acts as the bridge between the **GUI** and the **dsPIC**, enabling **wireless communication** over WiFi. It is programmed using the **Arduino IDE**.

### `wifi_code.ino`

- Sets up the **WiFi connection** (SSID, password, and network config).
- Listens for incoming requests (from PC GUI or smartphone).
- Forwards received commands to the dsPIC via **UART interface**.
- Acts as a transparent relay to support wireless control of the dsPIC.
  
---

## System Overview Diagram

    [GUI] ← WiFi → [ESP32] ←UART→ [dsPIC33AK128MC106]
                                      |
                  ┌───────────────────┼────────────────────┐
                  ▼                   ▼                    ▼
              [Multiplexer]     [Electronic Switch]     [ADC/DAC]

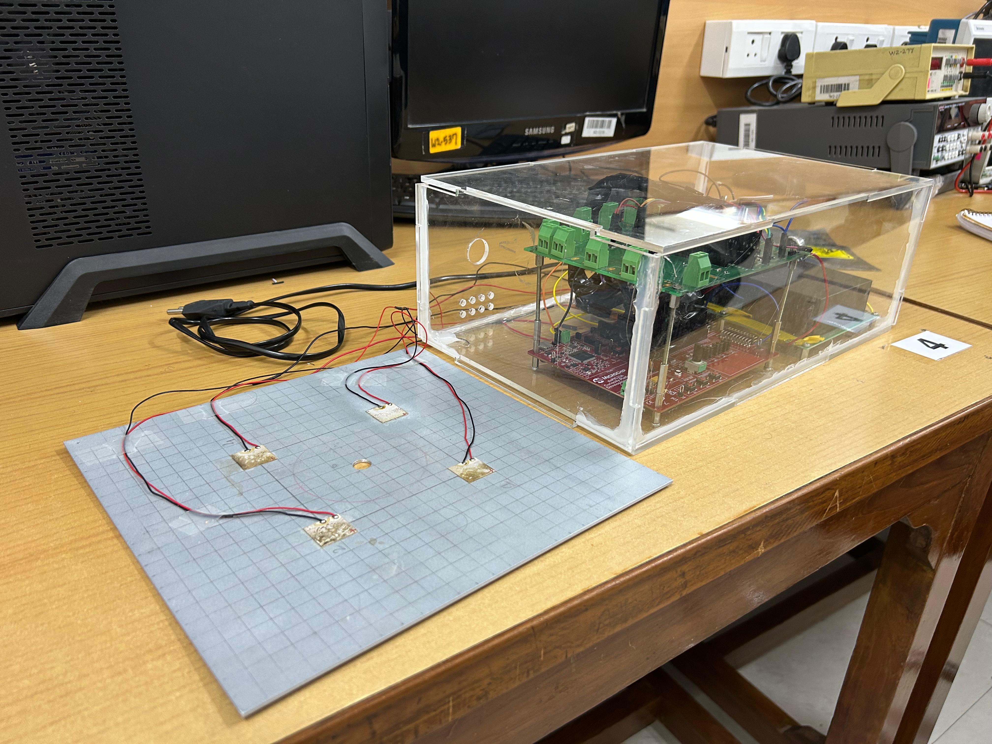
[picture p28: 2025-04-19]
images/OV_main_2.jpg

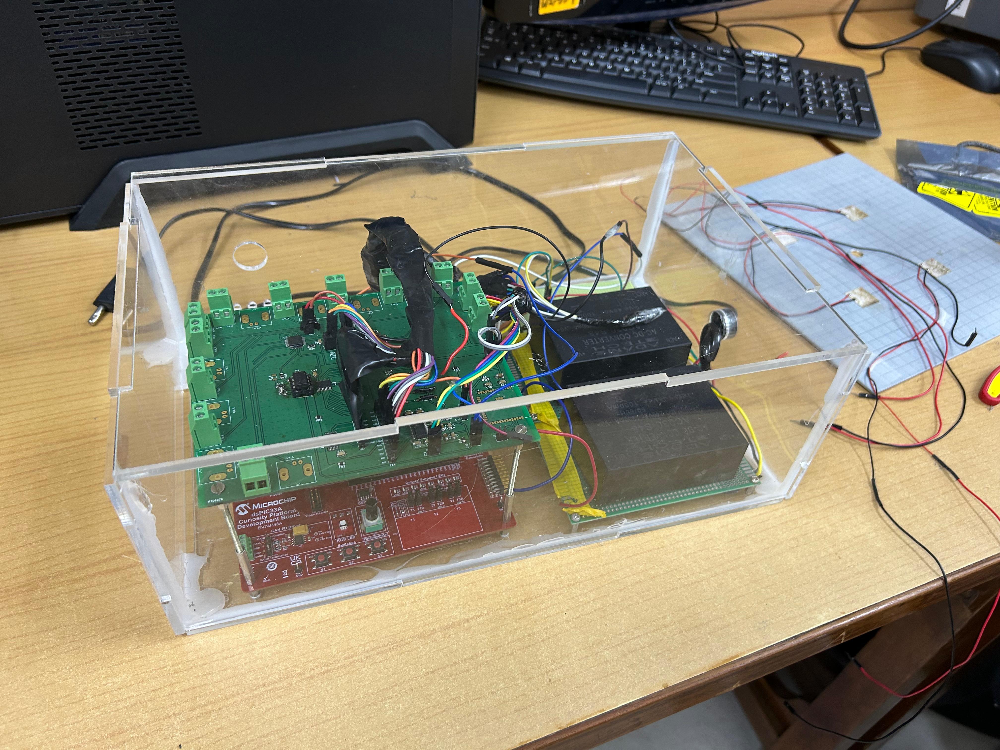
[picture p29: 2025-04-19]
images/OV_1.jpg

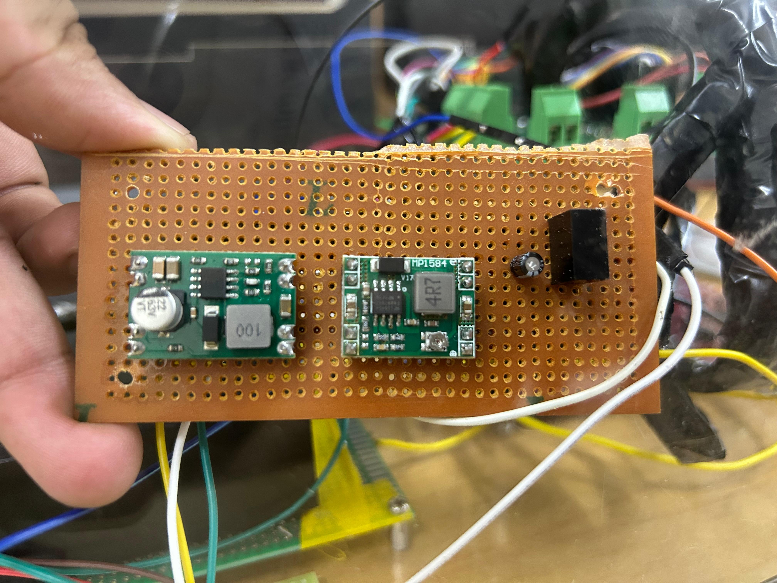
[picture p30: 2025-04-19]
images/power_supply.jpg

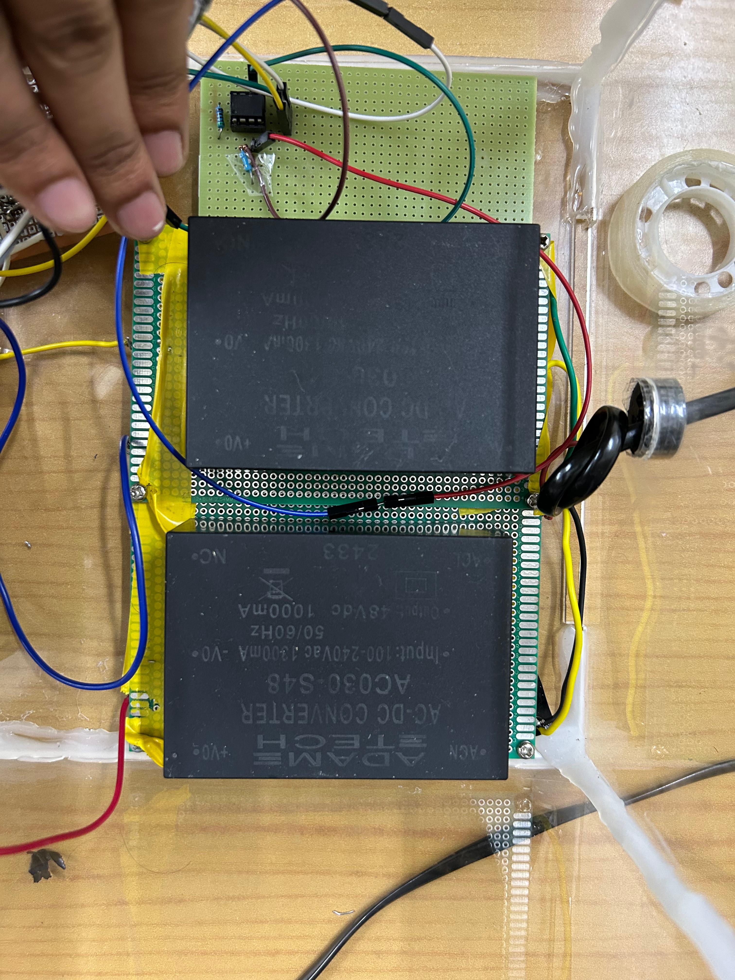
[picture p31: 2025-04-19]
images/SMPS.jpg

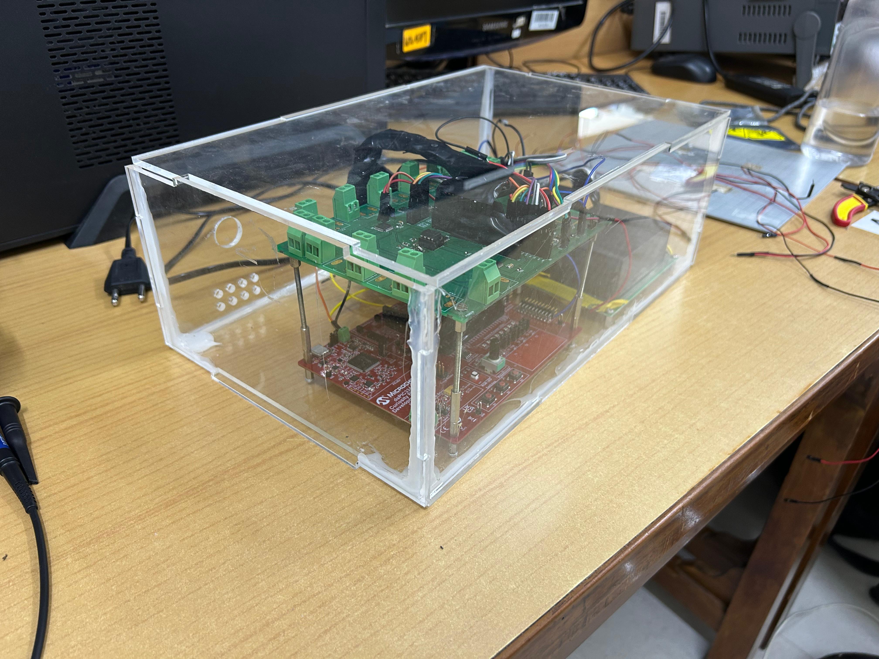
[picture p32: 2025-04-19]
images/OV_2.jpg

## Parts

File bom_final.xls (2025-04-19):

Component Name | Type | Quantity | Part Number | Supplier/Manufacturer/Vendor/Purchased Place | Cost | Description | Link
ESP32 wifi module | IC | 1 | ESP32 U4WDH | Robu | ₹870.00 | wifi module | https://robu.in/product/espressif-esp32-devkitc-esp32-wroom-32ue-development-board/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
Microcontroller DIM Module | IC | 1 | EV02G02A | Microchip | ₹2354.00 | Microcontroller | https://www.microchip.com/en-us/development-tool/ev02g02a
Microcontroller developemnet Board | IC | 1 | EV74H48A | Microchip | ₹6863.00 | Development Board | https://www.microchip.com/en-us/development-tool/EV74H48A
DAC | IC | 1 | DAC7821IPWR | Mouser | ₹653.00 | Digital to Analog Converter | https://www.mouser.in/ProductDetail/Texas-Instruments/DAC7821IPWR?qs=vul0MlC%2Fa1fjuC3krpTQeg%3D%3D
ADC | IC | 1 | MAX1426EAI+ | DigiKey | ₹978.00 | Analog to Digital Converter | https://www.digikey.in/en/products/detail/analog-devices-inc-maxim-integrated/MAX1426EAI/2137405
SMPS | Module | 2 | AC030-S48 | DigiKey | ₹3881.00 | Isolated AC-DC Converter | https://www.digikey.in/en/products/detail/adam-tech/AC030-S48/22469420
INA 128 | IC | 1 | INA 128 | Robu | ₹279.00 | Instrumentation Amplifier | https://robu.in/product/ina128-ic-smd-package-low-power-instrumentation-amplifier-ic/
PZT Transducer | Sensor | 8 | SP-5H | CPS Lab | ₹40000.00 | PZT Sensor (SP-5H) | NA
Buck converter 48v to 12v | Module | 1 | NA | Robu | ₹376.00 | DC-DC Step Down Power Supply Module | https://robu.in/product/dc-dc-dc8-55v-to-12v-2a-step-down-buck-module-regulated-power-supply-module-2a-high-current-circuit-board/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
Buck Converter 12v to 5v | Module | 1 | MP1584EN | Robu | ₹54.00 | DC-DC Step Down Power Supply Module | https://robu.in/product/mp1584en-dc-dc-3a-5v-12v-24v-to-12v-step-down-power-supply-module/?gad_source=1
Isolated Boost Converter 5v to 12v | Module | 1 | B0512S-1W | Robu | ₹109.00 | Isolated Booster Power Module | https://robu.in/product/k-cut-b0512s/
MUX | IC | 1 | TMUX8108PWR | Mouser | ₹737.00 | Multiplexer | https://www.mouser.in/ProductDetail/Texas-Instruments/TMUX8108PWR
Electronic Switch | IC | 1 | HV232FG-G | DigiKey | ₹1922.00 | Electronic Switch | https://www.digikey.in/en/products/detail/microchip-technology/HV232FG-G/4902466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
TL072 Opamp | IC | 1 | TL072CP | Robu | ₹39.00 | TL072 | https://robu.in/product/tl072cp/
PCB Fabrication | PCB | 1 | NA | PCB Power | ₹3300.00 | Fabricated PCB | NA
Acrylic Sheet Panels | Laser Cut | 6 | NA | WEL | NA | Laser cut panels for encasing | NA
 |  |  |  |  | ₹62415.00

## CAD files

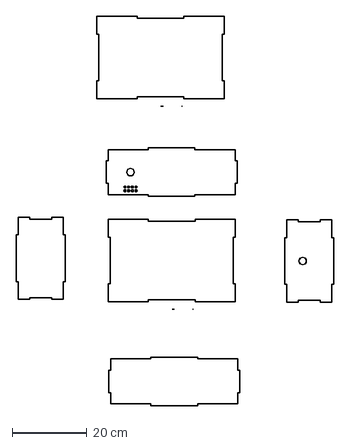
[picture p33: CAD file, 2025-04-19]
3d_models/box_model.dxf
84.8 x 104.2 cm

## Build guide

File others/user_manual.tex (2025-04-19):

\documentclass[12pt]{article}
\usepackage[a4paper,margin=0.6in]{geometry}
\usepackage{titlesec}
\usepackage{graphicx}
\usepackage{enumitem}
\usepackage{caption}
\usepackage{hyperref}
\titleformat{\section}{\Large\bfseries}{\thesection}{1em}{}
\title{\textbf{{\Huge{EcoSync 8X}\\ \Large{USER MANUAL}}}}
\author{}
\date{}

\begin{document}

\maketitle
\begin{figure}[h]
    \centering
    
    \caption*{dsPIC33A microcontroller based ultrasonic guided wave structural health monitoring system}
\end{figure}
\section*{Detailed Setup Instructions}

\begin{enumerate}[label=\textbf{Step \arabic*:}, leftmargin=2.5em]

\item \textbf{Connect piezoelectric sensors to the plate in an organized manner.}
\\$\bullet$ Mount each piezoelectric sensor firmly on the surface of the test plate according to your sensor layout plan.\\ $\bullet$ Ensure consistent spacing if required and align sensors to match the coordinate reference for accurate mapping.\\ Label or note the position of each sensor for easy identification when assigning them as transmitters or receivers later in the application.\\$\bullet$ Use strong adhesive or proper fixtures to ensure good mechanical coupling between the sensors and the plate for efficient wave transmission and reception.

\item \textbf{Connect the plug to a 220V, 15A supply socket.} \\
$\bullet$Locate a stable and grounded 220-volt AC power outlet rated for 15 amps.\\$\bullet$ Connect the system's power plug securely to the socket.\\ $\bullet$Ensure there’s no physical damage to the plug or socket, and avoid using loose or multi-plug extensions that could cause overheating or voltage drops.\\$\bullet$ This power supply will energize the signal generation and data acquisition units within the system.

\item \textbf{Connect your computer to the Wi-Fi module.}\\$\bullet$ Turn on the Wi-Fi of your computer and connect to the access point broadcast by the Wi-Fi module connected to the control box.\\$\bullet$ No internet connection is needed; this local connection is for direct data communication between your system and the application.\\$\bullet$ Ensure that that your computer's firewall or antivirus software does not block the communication port used by the application.

\item \textbf{Open your application and enter which piezoelectric sensors you want to use as transmitters and receivers.} \\
$\bullet$Launch the custom SHM (Structural Health Monitoring) software on your computer.\\$\bullet$ Once it detects the connected Wi-Fi module, the user interface will allow you to assign roles to each sensor (Tx/Rx).\\$\bullet$ Transmitters send the ultrasonic signal, while receivers capture the reflected waves that interact with potential defects.\\$\bullet$ Select sensors strategically to cover the full structure or specific areas of interest. This configuration directly affects the resolution and accuracy of damage detection.\\

\item \textbf{Data will be received over Wi-Fi after some time. Press the orange button to get the DI Map.} \\
$\bullet$After transmission, the system will gather signal responses from the receivers and process them onboard or via your computer. Data is sent wirelessly back to the computer and might take a few seconds depending on the number of sensors and sampling rate.\\$\bullet$ Once data is received and processed, click the \textbf{orange button} on the application interface to generate the \textbf{Damage Index (DI) Map}. This map visually represents possible damage areas based on signal attenuation, scattering, or time delay.

\end{enumerate}

\section*{Precautions}

\begin{itemize}
    \item \textbf{Do not touch the wiring or control box when plugged in to avoid electric shock.} \\
    High-voltage components inside the control box could pose a risk of shock. Make all sensor connections and hardware checks \textit{before} plugging the system in. If adjustment is needed while powered, use insulated tools and gloves, or power off first.

    \item \textbf{Handle the control box with care during transportation.} \\
    The control box contains delicate electronics such as amplifiers, ADCs, microcontrollers, or signal conditioning boards. Use padding or a protective case during transport to prevent mechanical damage. Avoid placing heavy objects on top of the box or exposing it to moisture or extreme heat.
\end{itemize}

\end{document}

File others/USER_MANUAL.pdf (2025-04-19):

# EcoSync 8X

## USER MANUAL


dsPIC33A microcontroller based ultrasonic guided wave structural health monitoring system

## Detailed Setup Instructions

Step 1: Connect piezoelectric sensors to the plate in an organized manner.
- Mount each piezoelectric sensor firmly on the surface of the test plate according to your sensor layout plan.
- Ensure consistent spacing if required and align sensors to match the coordinate reference for accurate mapping.
Label or note the position of each sensor for easy identification when assigning them as transmitters or receivers later in the application.
- Use strong adhesive or proper fixtures to ensure good mechanical coupling between the sensors and the plate for efficient wave transmission and reception.
Step 2: Connect the plug to a 220V, 15A supply socket. •Locate a stable and grounded 220-volt AC power outlet rated for 15 amps.
- Connect the system’s power plug securely to the socket.
•Ensure there’s no physical damage to the plug or socket, and avoid using loose or multi-plug extensions that could cause overheating or voltage drops.
- This power supply will energize the signal generation and data acquisition units within the system.

1

Step 3: Connect your computer to the Wi-Fi module.
- Turn on the Wi-Fi of your computer and connect to the access point broadcast by the Wi-Fi module connected to the control box.
- No internet connection is needed; this local connection is for direct data communication between your system and the application.
- Ensure that that your computer’s firewall or antivirus software does not block the communication port used by the application.
Step 4: Open your application and enter which piezoelectric sensors you want to use as transmitters and receivers.
•Launch the custom SHM (Structural Health Monitoring) software on your computer.
- Once it detects the connected Wi-Fi module, the user interface will allow you to assign roles to each sensor (Tx/Rx).
- Transmitters send the ultrasonic signal, while receivers capture the reflected waves that interact with potential defects.
- Select sensors strategically to cover the full structure or specific areas of interest. This configuration directly affects the resolution and accuracy of damage detection.
Step 5: Data will be received over Wi-Fi after some time. Press the orange button to get the DI Map.
•After transmission, the system will gather signal responses from the receivers and process them onboard or via your computer. Data is sent wirelessly back to the computer and might take a few seconds depending on the number of sensors and sampling rate.
- Once data is received and processed, click the orange button on the application interface to generate the Damage Index (DI) Map. This map visually represents possible damage areas based on signal attenuation, scattering, or time delay.

## Precautions

- Do not touch the wiring or control box when plugged in to avoid electric shock. High-voltage components inside the control box could pose a risk of shock. Make all sensor connections and hardware checks before plugging the system in. If adjustment is needed while powered, use insulated tools and gloves, or power off first.
- Handle the control box with care during transportation.
The control box contains delicate electronics such as amplifiers, ADCs, microcontrollers, or signal conditioning boards. Use padding or a protective case during transport to prevent mechanical damage. Avoid placing heavy objects on top of the box or exposing it to moisture or extreme heat.

2

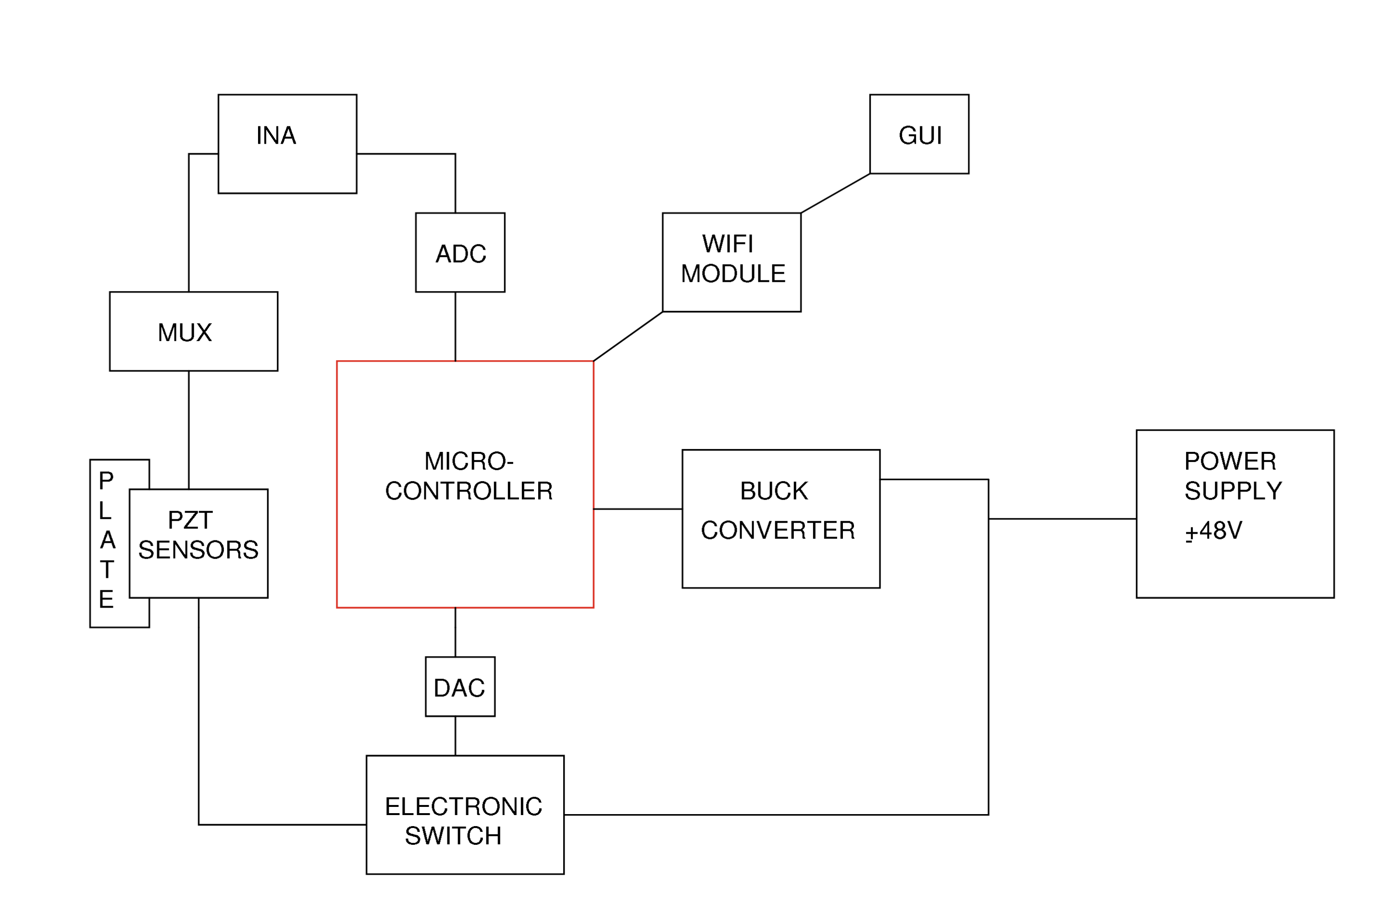
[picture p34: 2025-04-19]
others/extras/wiring_diagram.png

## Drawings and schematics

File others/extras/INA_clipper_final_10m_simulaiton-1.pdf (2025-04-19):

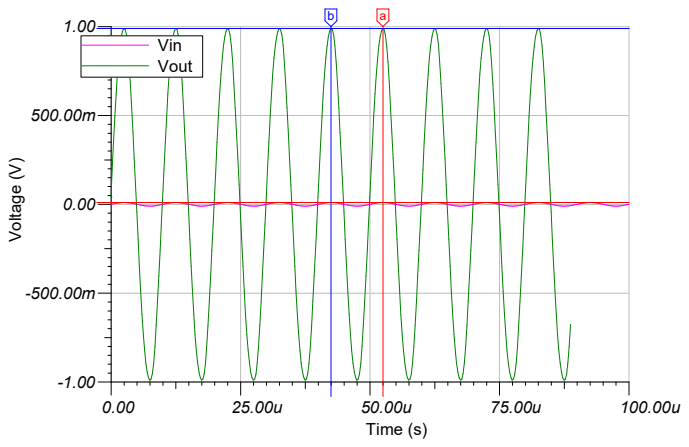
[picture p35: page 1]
Time (s); 100.00u Voltage ⁽V⁾; Vin Vout

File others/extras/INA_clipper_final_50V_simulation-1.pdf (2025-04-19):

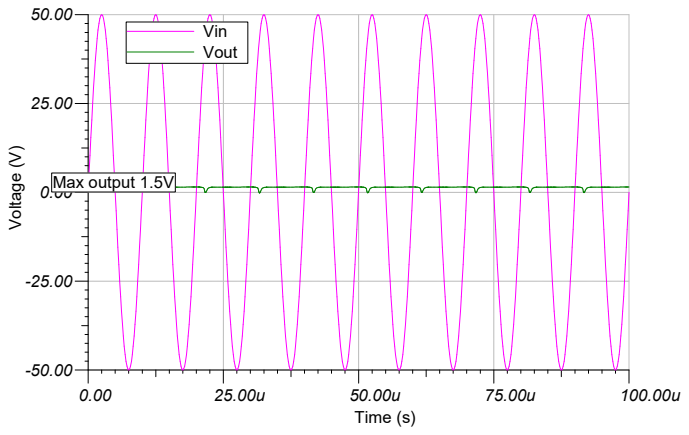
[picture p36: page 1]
Time (s); 100.00u Voltage ⁽V⁾; Max output 1.5V; Vin Vout

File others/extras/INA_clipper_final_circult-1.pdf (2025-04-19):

# INA + Clipper

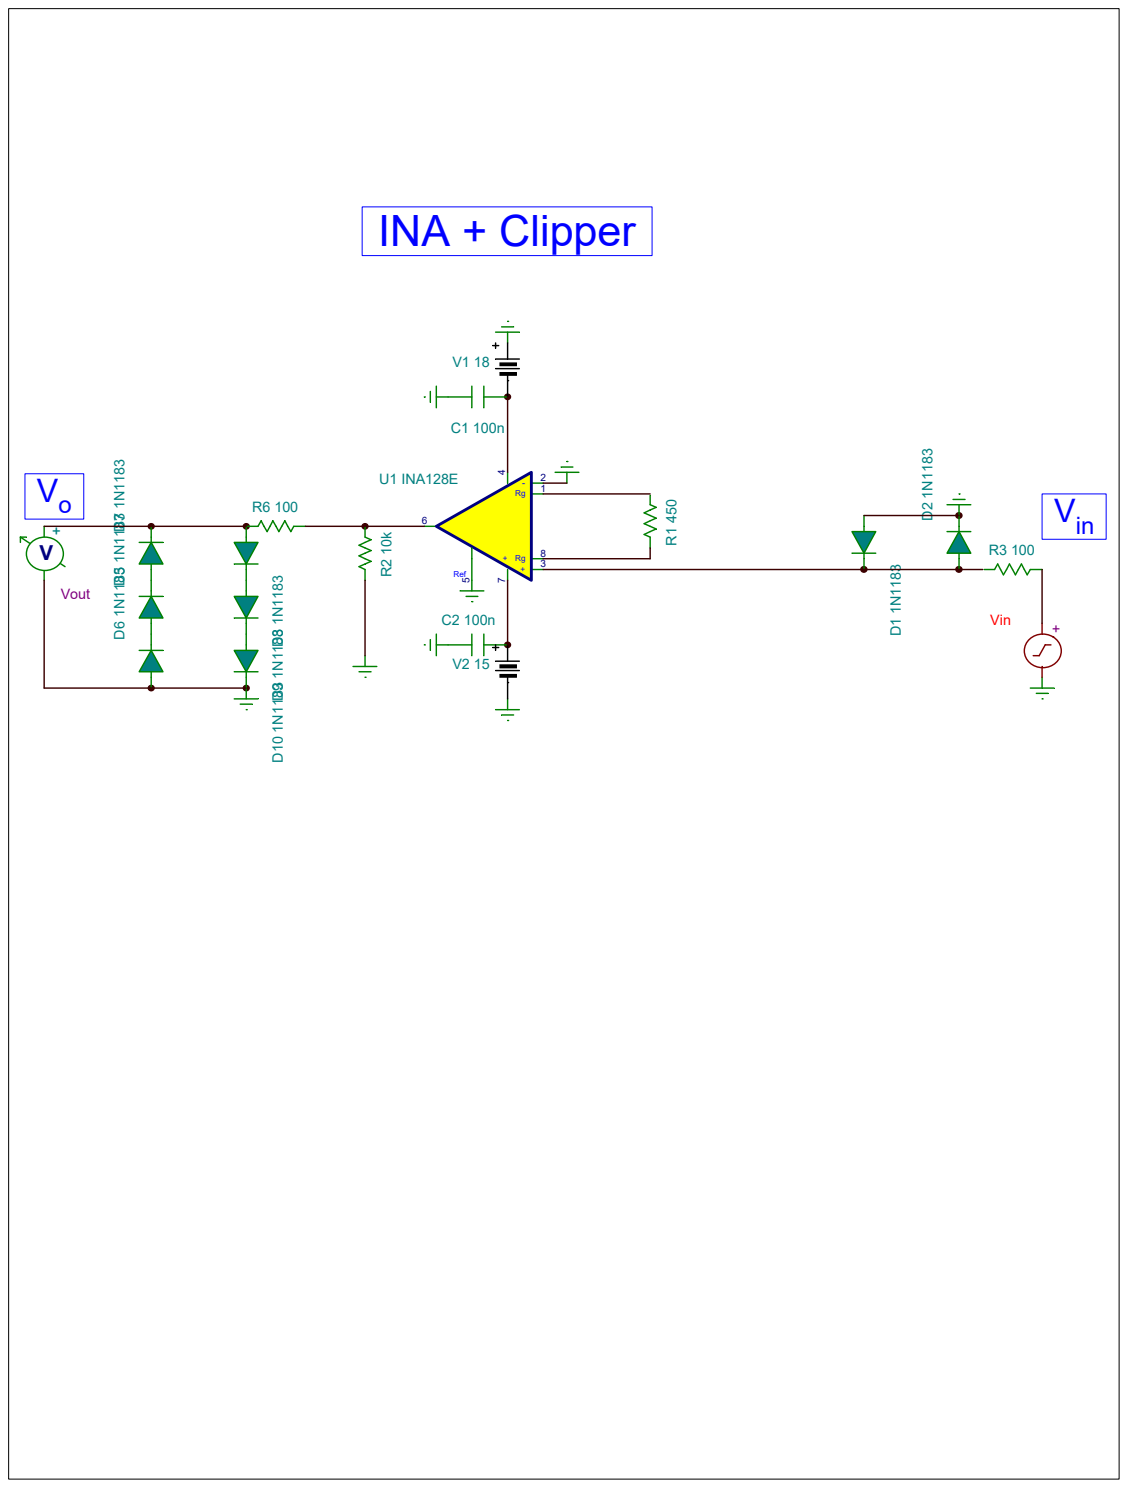
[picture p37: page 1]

R3 100 D² ¹N¹¹⁸³ D¹ ¹N¹¹⁸³ C2 100n

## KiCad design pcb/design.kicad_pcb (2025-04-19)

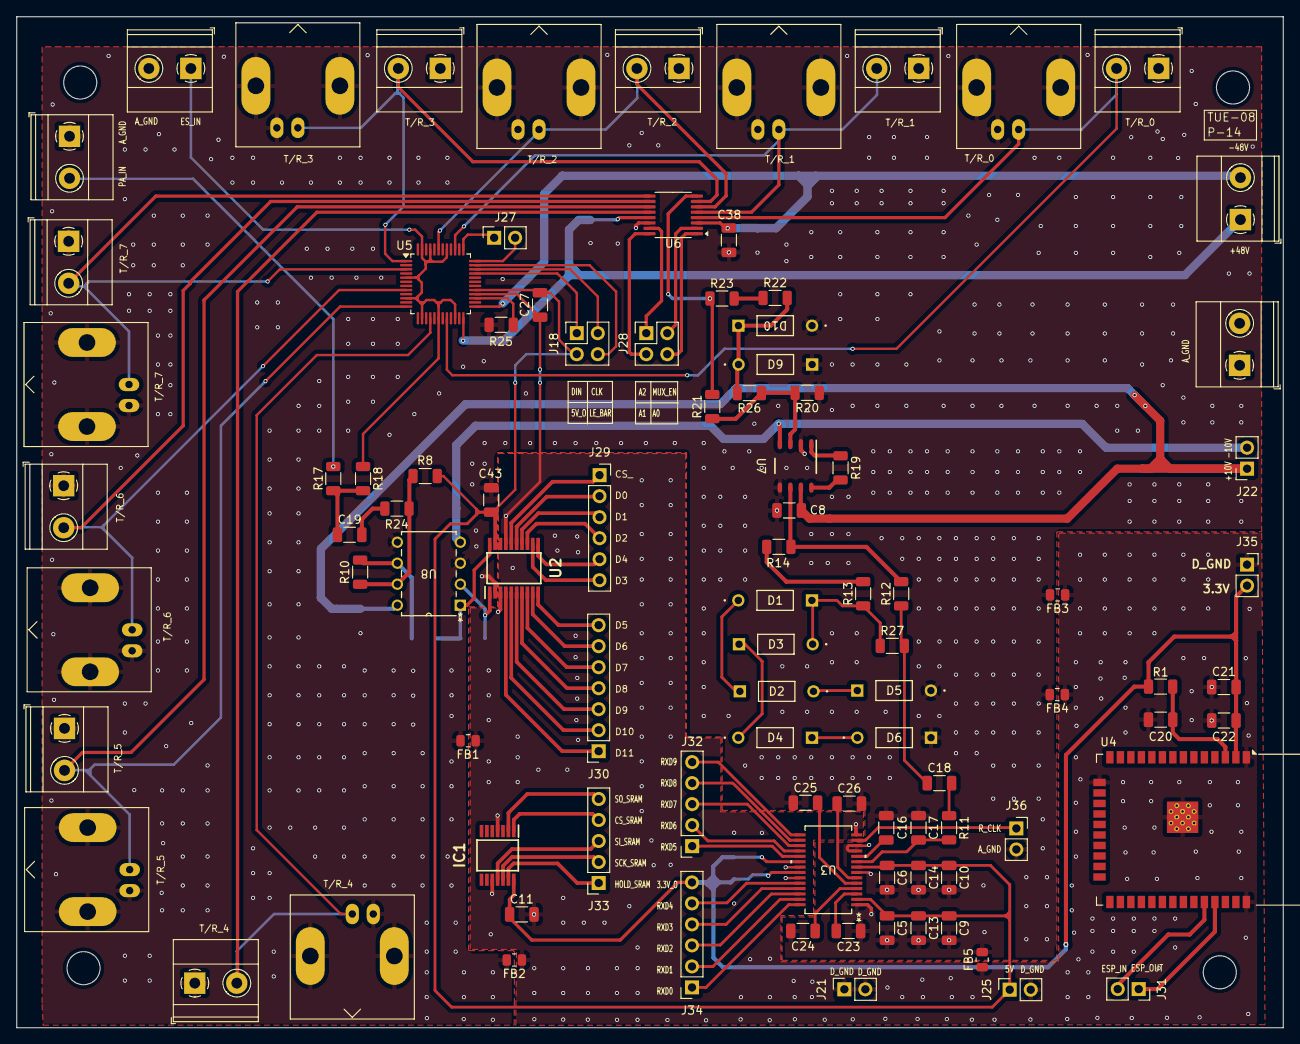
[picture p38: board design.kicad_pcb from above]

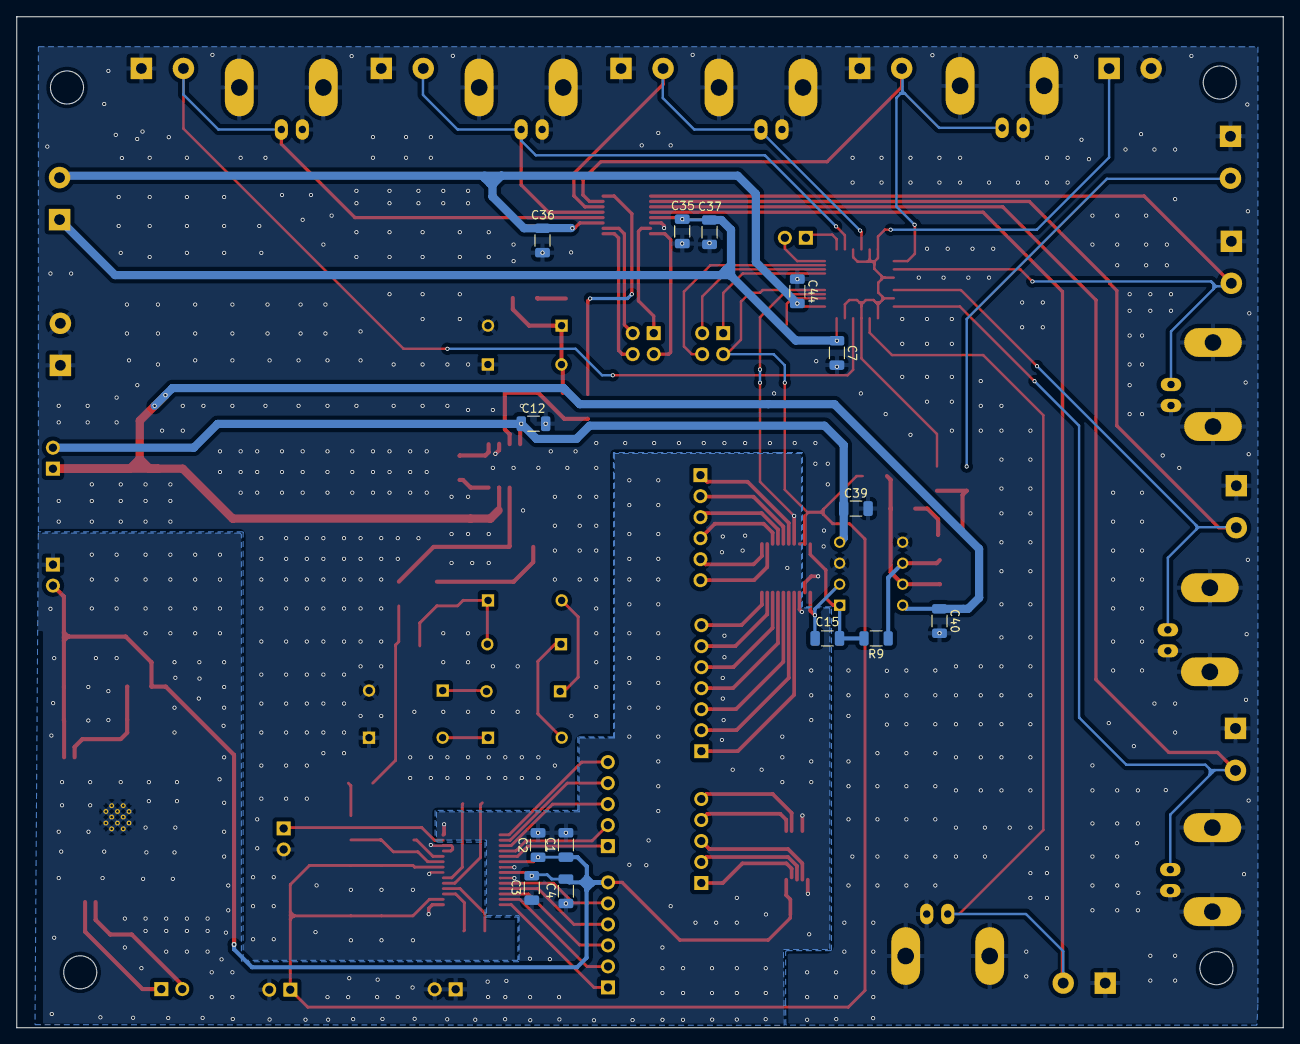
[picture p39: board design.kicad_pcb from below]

Board: 2 copper layers, 153.2 x 122.3 mm, 109 parts (14 on the bottom side), 87 nets.

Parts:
A_GND: Screw_Terminal_01x02; TerminalBlock_Phoenix_MKDS-1,5-2-5.08_1x02_P5.08mm_Horizont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
C1, C3, C13, C14: 2.2uf; C_1206_3216Metric
C2, C4, C8, C9, C10, C11, C12, C16, C18, C19, C23, C24, C25, C26, C27, C39, C40, C43, C44: 0.1uf; C_1206_3216Metric
C5, C6: 100pf; C_1206_3216Metric
C7, C37, C38: 0.1u; C_1206_3216Metric
C15: C; C_1206_3216Metric
C17: 22fp; C_1206_3216Metric
C20, C22: 0.1uF; C_1206_3216Metric
C21: 10uF; C_1206_3216Metric
C35, C36: 1u; C_1206_3216Metric
D1, D2, D3, D4, D5, D6, D9, D10: D; 1n914
FB1, FB2, FB3, FB4, FB5: FerriteBead; R_0805_2012Metric
IC1: 23LCV04M-I_ST; SOP65P640X120-14N
J2, J3, J4, J5, J6, J7, J8, J9: Conn_Coaxial; BNC_Amphenol_B6252HB-NPP3G-50_Horizontal
J10, J11, J12, J13, J14, J15, J16, J17, J19, J20, J23: Screw_Terminal_01x02; TerminalBlock_Phoenix_MKDS-1,5-2-5.08_1x02_P5.08mm_Horizont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
J18, J28: Conn_02x02_Top_Bottom; PinSocket_2x02_P2.54mm_Vertical
J21, J22, J25, J27, J31, J35, J36: Conn_01x02; PinSocket_1x02_P2.54mm_Vertical
J29, J34: Conn_01x06; PinSocket_1x06_P2.54mm_Vertical
J30: Conn_01x07; PinSocket_1x07_P2.54mm_Vertical
J32, J33: Conn_01x05; PinSocket_1x05_P2.54mm_Vertical
R1, R8, R10, R20: 10k; R_1206_3216Metric
R9: 5k; R_1206_3216Metric
R11: 50; R_1206_3216Metric
R12, R14, R17, R18, R21, R23, R25, R26, R27: 0; R_1206_3216Metric
R13, R19, R22: 100; R_1206_3216Metric
R24: 180; R_1206_3216Metric
U2: DAC7821IPWR; SOP65P640X120-20N
U3: MAX1426EAI+; adc
U4: ESP32-WROOM-32DM113DH6400PH3Q0; ESP32-WROOM-32D
U5: HV232FG-G; LQFP-48_7x7mm_P0.5mm
U6: TMUX8108PWR; TSSOP-16_4.4x5mm_P0.65mm
U7: INA128PA; ina128
U8: TL072CP; tl072

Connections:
+3.3V: C1.1, C2.1, C3.1, C4.1, C11.1, C21.2, C22.2, IC1.14 (VCC), J34.6, J35.2, R1.2, U3.20 (DVDD), U3.22 (DVDD), U4.2 (3V3)
+5V: C5.1, C6.1, C9.1, C10.1, C13.1, C14.1, C27.2, C43.2, J18.2, J25.1, R8.1, U2.18 (VDD), U2.19 (VREF), U3.2 (AVDD), U3.8 (AVDD), U5.29 (VDD)
+10V: C8.2, C40.1, J22.1, U7.7 (V+), U8.8 (VCC+)
+48V: C7.1, C35.1, C37.1, J23.1, U5.24 (VPP), U6.13 (VDD)
-10V: C12.1, C39.1, J22.2, U7.4 (V-), U8.4 (VCC-)
-48V: C36.2, C38.2, C44.2, J23.2, U5.25 (VNN), U6.3 (VSS)
A0: J28.4, U6.1 (A0)
A1: J28.2, U6.16 (A1)
A2: J28.1, U6.15 (A2)
A_GND: A_GND.1, C5.2, C6.2, C7.2, C8.1, C9.2, C10.2, C12.2, C13.2, C14.2, C16.1, C17.2, C23.2, C24.2, C25.2, C26.2, C35.2, C36.1, C37.2, C38.1, C39.2, C40.2, C43.1, C44.1, D5.1 (K), D6.2 (A), D9.2 (A), D10.1 (K), FB1.2, FB2.2, FB3.2, FB4.2, FB5.2, J2.2 (Ext), J3.2 (Ext), J4.2 (Ext), J5.2 (Ext), J6.2 (Ext), J7.2 (Ext), J8.2 (Ext), J9.2 (Ext), J10.1, J11.1, J12.1, J13.1, J14.1, J15.1, J16.1, J17.1, J19.1, J19.2, J20.2, J36.2, R20.1, R25.2, U2.2 (IOUT2), U3.1 (AGND), U3.7 (AGND), U3.11 (CMLP), U3.12 (CMLN), U6.14 (GND), U7.2 (V-IN), U7.5 (REF), U8.3 (1IN+), U8.5 (2IN+)
CLK: J18.3, U5.34 (CLK)
CLR: J27.2, U5.36 (CLR)
CS_: J29.1, U2.16 (CS_N)
CS_SRAM: IC1.1 (~CS), J33.4
D0: J29.2, U2.15 (DB0_LSB)
D1: J29.3, U2.14 (DB1)
D2: J29.4, U2.13 (DB2)
D3: J29.6, U2.12 (DB3)
D4: J29.5, U2.11 (DB4)
D5: J30.7, U2.10 (DB5)
D6: J30.6, U2.9 (DB6)
D7: J30.5, U2.8 (DB7)
D8: J30.4, U2.7 (DB8)
D9: J30.3, U2.6 (DB9)
D10: J30.2, U2.5 (DB10)
D11: J30.1, U2.4 (DB11_MSB)
DAC_OUT: C19.1, R17.2, R18.2
DIN: J18.1, U5.33 (DIN)
DOUT: J27.1, U5.37 (DOUT)
D_GND: C1.2, C2.2, C3.2, C4.2, C11.2, C20.1, C21.1, C22.1, C27.1, FB1.1, FB2.1, FB3.1, FB4.1, FB5.1, IC1.4 (VSS), IC1.10 (VBAT), J21.1, J21.2, J25.2, J35.1, U2.3 (GND), U2.17 (R_W_N), U3.14 (*OE/PD), U3.21 (DGND), U3.23 (DGND), U4.1 (GND), U4.15 (GND), U4.38 (GND), U4.39 (GND), U5.28 (GND)
ESP_DATA_IN: J31.2, U4.34 (RXD0)
ESP_DATA_OUT: J31.1, U4.35 (TXD0)
ES_IN: J20.1, R18.1, U5.5 (SW4), U5.10 (SW3), U5.14 (SW2), U5.18 (SW1), U5.22 (SW0), U5.41 (SW7), U5.45 (SW6), U5.47 (SW5)
HOLD_SRAM: IC1.13 (~HOLD/SIO3), J33.1
INA_OUT: C18.1, R12.1, R27.2
INN: C16.2, U3.10 (INN)
INP: C17.1, R11.2, U3.9 (INP)
LE_BAR: J18.4, U5.35 (*LE)
MUX_EN: J28.3, U6.2 (EN)
MUX_OUT: R21.2, R23.2, U6.8 (D)
unnamed: C18.2, R11.1
unnamed: C19.2, R24.2
unnamed: D1.2 (A), D3.1 (K), R13.1, R27.1
unnamed: D1.1 (K), D2.2 (A)
unnamed: D2.1 (K), D5.2 (A)
unnamed: D3.2 (A), D4.1 (K)
unnamed: D4.2 (A), D6.1 (K)
unnamed: D9.1 (K), D10.2 (A), R22.2, R26.2
unnamed: R13.2, R14.1
unnamed: R19.1, U7.1 (RG)
unnamed: R19.2, U7.8 (RG)
unnamed: R22.1, R23.1
unnamed: C15.2, U2.1 (IOUT1), U8.2 (1IN-)
unnamed: C15.1, R9.1, U2.20 (RFB), U8.1 (1OUT)
unnamed: C20.2, R1.1, U4.3 (EN)
unnamed: R25.1, U5.27 (RGND)
unnamed: R20.2, R21.1, R26.1, U7.3 (V+IN)
unnamed: R12.2, R14.2, U7.6 (VO)
unnamed: R9.2, R10.1, U8.6 (2IN-)
unnamed: R8.2, R10.2, R24.1, U8.7 (2OUT)
PA_IN: A_GND.2, R17.1
RXD0: J34.1, U3.28 (D0)
RXD1: J34.2, U3.27 (D1)
RXD2: J34.3, U3.26 (D2)
RXD3: J34.4, U3.25 (D3)
RXD4: J34.5, U3.24 (D4)
RXD5: J32.1, U3.19 (D5)
RXD6: J32.2, U3.18 (D6)
RXD7: J32.3, U3.17 (D7)
RXD8: J32.4, U3.16 (D8)
RXD9: J32.5, U3.15 (D9)
R_CLK: J36.1, U3.13 (CLK)
R_CML: C26.1, U3.6 (CML)
R_REFIN: C24.1, U3.4 (REFIN)
R_REFN: C25.1, U3.5 (REFN)
R_REFP: C23.1, U3.3 (REFP)
SCK_SRAM: IC1.12 (SCK), J33.2
SI_SRAM: IC1.11 (SI/SIO0), J33.3
SO_SRAM: IC1.2 (SO/SIO1), J33.5
T/R_0: J2.1 (In), J10.2, U5.20 (SW0), U6.4 (S1)
T/R_1: J3.1 (In), J11.2, U5.39 (SW7), U6.5 (S2)
T/R_2: J4.1 (In), J12.2, U5.43 (SW6), U6.6 (S3)
T/R_3: J5.1 (In), J13.2, U5.1 (SW5), U6.7 (S4)
T/R_4: J6.1 (In), J14.2, U5.16 (SW1), U6.12 (S5)
T/R_5: J7.1 (In), J15.2, U5.12 (SW2), U6.11 (S6)
T/R_6: J8.1 (In), J16.2, U5.8 (SW3), U6.10 (S7)
T/R_7: J9.1 (In), J17.2, U5.3 (SW4), U6.9 (S8)

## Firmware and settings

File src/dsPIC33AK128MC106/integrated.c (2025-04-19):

#include <xc.h>                         // Include processor header
#include <stdio.h>                      // For printf and snprintf
#include <stdint.h>                     // For uint types
#include <stdlib.h>                     // For standard utilities
#define FCY 100000000UL                 // Define instruction cycle frequency (Fosc/2 = 200MHz / 2)
#include <libpic30.h>                   // For __delay_us and other helpers
#include <math.h>                       // Math operations
#include "mcc_generated_files/system/clock.h"  // Clock initialization
#include "protocol_def.h"                      // For cmd protocol
// Define ports for DAC and multiplexer
#define DATA_PORT LATA        
#define DATA_TRIS TRISA       

// Define control lines for 3-bit multiplexer
#define MUX_A0 LATAbits.LATA9
#define MUX_A1 LATAbits.LATA10
#define MUX_A2 LATAbits.LATA2
#define MUX_EN LATAbits.LATA3

// Define DAC chip select and data lines
#define DAC_CSn LATDbits.LATD12
#define DAC_data LATD

// Define ADC data and clock lines
#define ADC_data LATC
#define ADC_clk LATAbits.LATA4

// Define Chip Select line for digital logic
#define CS_TRIS  TRISCbits.TRISC0
#define CS_LAT  LATCbits.LATC0
    
#define BAUDRATE 9600                   // UART baudrate
#define BRGVAL (((FCY / BAUDRATE) / 16) - 1)  // Calculate UART baud rate register value

// Define shift register connections (Edge Sequencer)
#define ES_DIN LATAbits.LATA8
#define ES_CLK LATAbits.LATA11
#define ES_LEn LATAbits.LATA1
#define ES_CLR LATAbits.LATA7
#define ES_DOUT LATAbits.LATA0

// UART receiver initialization
void uart_rx_init() {
    _U1RXR = 59;                        // Map RX to RP59
    U1CONbits.MODE = 0;                // 8-bit UART, asynchronous mode
    U1CONbits.BRGS = 0;                // Low speed baud
    U1CONbits.CLKSEL = 0;              // Use system clock/2
    U1CONbits.STP = 0;                 // 1 stop bit
    U1BRG = BRGVAL;                    // Set baud rate
    U1CONbits.ON = 1;                  // Enable UART module
    U1CONbits.RXEN = 1;                // Enable RX
}

// UART transmitter initialization
void uart_tx_init() {
    _RP58R = 9;                        // Map TX to RP58
    U1CONbits.TXEN = 1;               // Enable TX
}

// Transmit a single character over UART
void uart_transmit_char(char c) {
    while (U1STATbits.UTXBF);         // Wait if TX buffer full
    U1TXB = c;                         // Load character to TX buffer
}

// Transmit a null-terminated string over UART
void uart_transmit_string(const char *str) {
    while (*str) {
        uart_transmit_char(*str++);   // Send each character
    }
}

// Transmit an integer as a string
void uart_transmit_no(const uint16_t data) {
    char buffer[20];
    snprintf(buffer, sizeof(buffer), "%d", data);  // Convert to string
    uart_transmit_string(buffer);                  // Send string
}

// Hanning window (50 points)
const uint16_t hanningTable[50] = {
    0x800,0x812,0x842,0x872,0x867,0x7EF,0x718,0x641,0x5F9,0x6B1,
    0x867,0xA87,0xC12,0xC17,0xA36,0x6F0,0x38F,0x19E,0x233,0x554,
    0x9E1,0xDF8,0xFCF,0xE81,0xA85,0x57B,0x17F,0x031,0x208,0x61F,
    0xAAC,0xDCD,0xE62,0xC71,0x910,0x5CA,0x3E9,0x3EE,0x579,0x799,
    0x94F,0xA07,0x9BF,0x8E8,0x811,0x799,0x78E,0x7BE,0x7EE,0x800
};

// Sine wave (20 points)
const uint16_t sineTable[20] = {
    0x7fd, 0x814, 0x829, 0x83a, 0x844, 0x848, 0x844, 0x83a,
    0x829, 0x814, 0x7fd, 0x7e6, 0x7d1, 0x7c0, 0x7b6, 0x7b2,
    0x7b6, 0x7c0, 0x7d1, 0x7e6
};

// Function declarations
void DAC_init(void);
void DAC_write(uint16_t data);
void DAC_Controller(uint16_t amplitude);
void Timer1_Init(void);

volatile uint16_t cnt = 0;              // Toggle counter for DAC waveform
volatile uint16_t amplitude = 0xFFFF;   // Default amplitude

// Write 12-bit data to DAC
void DAC_write(uint16_t data) {
    DATA_PORT = (DATA_PORT & 0xF000) | (data & 0x0FFF);  // Mask upper bits
    __delay_us(1);
    CS_LAT = 0;             // Pull chip select low
    __delay_us(1);
    CS_LAT = 1;             // Pull chip select high
    __delay_us(1);
}

// Generate waveform using DAC
void DAC_Controller(uint16_t amplitude) {
    uint16_t normalized_value = (uint16_t)(((uint32_t)amplitude * 4095) / 65536);  // Scale to 12-bit
    uint16_t Data;

    if (cnt) {
        Data = normalized_value;
        __delay_us(1);
    }
    else {
        Data = 0;
        __delay_us(1);
    }
    cnt ^= 1;               // Toggle cnt
    DAC_write(Data);        // Send to DAC
}

// Initialize multiplexer control lines
void TMUX_init(){
    TRISAbits.TRISA9 =  0;
    TRISAbits.TRISA10 = 0;
    TRISAbits.TRISA2 =  0;
    TRISAbits.TRISA3 =  0; 
}

// Initialize DAC
void DAC_init(){
    TRISD = 0;              // Set PORTD as output
    DAC_CSn = 0;            // Enable DAC chip
}

// Control 3-bit address of multiplexer
void TMUX_Control(uint8_t address) {
    MUX_A0 = address & 0x01;
    MUX_A1 = (address & 0x02)>>1;
    MUX_A2 = (address & 0x04)>>2;
}

// Initialize ADC input and clock
void ADC_init(){
    TRISC = 0xFFF;          // Set PORTC as input
    TRISAbits.TRISA4 = 0;   // Set clock pin as output
    ADC_clk = 0;            // Initialize clock low
}

// Initialize edge sequencer shift register
void ES_init(){
    TRISAbits.TRISA8 = 0;   // DIN
    TRISAbits.TRISA11 = 0;  // CLK
    TRISAbits.TRISA1 = 0;   // LE
    TRISAbits.TRISA7 = 0;   // CLR
    TRISAbits.TRISA0 = 1;   // DOUT as input

    ES_LEn = 1;             // Disable latch
    ES_CLK = 0;
    ES_CLR = 0;             // Clear shift register
    __delay_us(1);
    ES_CLR = 1;             // Stop clearing
    __delay_us(1);
    ES_CLR = 0;             // Reassert
}

int main(void) {
    CLOCK_Initialize();     // Initialize system clock
    DAC_init();             // Initialize DAC
    TMUX_init();            // Initialize multiplexer
    MUX_EN = 1;             // Enable multiplexer
    TMUX_Control(MUX_data);        // Set MUX to channel 0
    ADC_init();             // Initialize ADC
    ES_init();              // Initialize edge sequencer

    uart_rx_init();         // Init UART RX
    uart_tx_init();         // Init UART TX

    // Edge sequencer bit pattern
    uint8_t es_seq[8];
    for(int i=0;i<8;i++){
    es_seq[i] = ES_data[i];}
    //uint8_t es_seq[8] = {0,1,0,0,0,0,0,0};  // Order of channels
    ES_LEn = 0;              // Enable shift register load
    __delay_us(10);
    for (int i = 0; i < 8; i++) {
        ES_DIN = es_seq[i];                 // Load bit
        __delay_us(10);
        ES_CLK = !ES_CLK;                   // Clock pulse high
        __delay_us(10);
        ES_CLK = !ES_CLK;                   // Clock pulse low
    }
    __delay_us(10);
    ES_LEn = 1;                             // Latch the sequence

    uint16_t recvd[400];                   // Store ADC values

    while(1){
        for (int i = 0; i < 50; i++) {
            DAC_data = hanningTable[i % 50] & 0x0fff; // Set DAC data
            __delay_us(1);
            DAC_CSn = !DAC_CSn;            // Toggle chip select
            DAC_CSn = !DAC_CSn;            // Toggle again

            ADC_clk = !ADC_clk;            // Toggle ADC clock
            // Read 10-bit ADC value from specific pins
            recvd[i] = (PORTCbits.RC11 << 9 | PORTCbits.RC10 << 8 | 
                        PORTCbits.RC8 << 7 | PORTCbits.RC7 << 6 |
                        PORTCbits.RC6 << 5 | PORTCbits.RC5 << 4 |
                        PORTCbits.RC4 << 3 | PORTCbits.RC3 << 2 |
                        PORTCbits.RC2 << 1 | PORTCbits.RC0) & 0x03ff;
        }
        __delay_us(50000);  // Delay for observation
    }

    for (int i = 50; i < 400; i++) {
        ADC_clk = !ADC_clk;            // Toggle ADC clock
        // Continue reading remaining ADC values
        recvd[i] = (PORTCbits.RC11 << 9 | PORTCbits.RC10 << 8 |
                    PORTCbits.RC8 << 7 | PORTCbits.RC7 << 6 |
                    PORTCbits.RC6 << 5 | PORTCbits.RC5 << 4 |
                    PORTCbits.RC4 << 3 | PORTCbits.RC3 << 2 |
                    PORTCbits.RC2 << 1 | PORTCbits.RC0) & 0x03ff;
    }

    // Transmit alternate ADC values over UART
    for (int i = 1; i < 400; i += 2) {
        uart_transmit_no(recvd[i]);
        uart_transmit_string(",");
    }

    while (1);  // Infinite loop
}

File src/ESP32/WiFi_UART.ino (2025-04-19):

#include <WiFi.h>

const char* ssid = "ESP32_AP";
const char* password = "12345678";
WiFiServer server(80);

void setup() {
  Serial.begin(115200);
  Serial2.begin(115200, SERIAL_8N1, 16, 17); // UART2: TX=16, RX=17
  
  WiFi.softAP(ssid, password);
  Serial.print("IP: "); Serial.println(WiFi.softAPIP());
  server.begin();
}

void loop() {
  WiFiClient client = server.available();
  if (client) {
    client.println("Connected! Type commands (RED/BLUE/GREEN):");
    
    while (client.connected()) {
      // PC → ESP32 → dsPIC
      if (client.available()) {
        char c = client.read();
        
        // Echo back to Putty
        client.print(c);
        Serial.println(c);
        // Forward to dsPIC
        Serial2.print(c);
        
        // Special handling for Enter key
        if (c == '\r' || c == '\n') {
          client.println(); // New line in Putty
          Serial.println();
          Serial2.println(); // Send line ending to dsPIC
        }
      }

      // dsPIC → ESP32 → PC
      if (Serial2.available()) {
        String uart_data = Serial2.readStringUntil('\n');
        client.println("dsPIC: " + uart_data);
      }
    }
    client.stop();
  }
}
